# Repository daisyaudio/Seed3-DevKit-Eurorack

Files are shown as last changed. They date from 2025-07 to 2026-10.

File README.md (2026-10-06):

# Seed3 Eurorack Dev Kit

Seed3 Eurorack Dev Kit

## A Eurorack Module Platform for the Daisy Seed3

The Seed3 Eurorack Dev Kit is the premier development board for building your next Eurorack module on the Daisy platform. Create powerful effects, stunning sound sources, and complex utilities, all on a single board.

The Dev Kit carries a host of hardware parameters, including 8 potentiometers, jacks for CV, gate, MIDI, and stereo audio I/O, 2 toggle switches, 2 tactile buttons, and a microSD card reader for sample playback, file generation, and data transfer. Mountable in a standard 3U Eurorack case, the Dev Kit integrates straight into your development rig so you can fully realize your next big Eurorack project.

---

## Contents

- [Features](#features)
- [Specifications](#specifications)
- [Getting Started](#getting-started)
- [Making Your Own Project](#making-your-own-project)
- [Hardware Reference](#hardware-reference)
- [Resources & Support](#resources--support)
- [Open-Source Hardware](#open-source-hardware)
- [License](#license)

---

## Features

| Category | Details |
| --- | --- |
| **Format** | 3U Eurorack, 28HP |
| **Audio** | Stereo audio input and output (AC-coupled) |
| **MIDI** | 3.5mm TRS MIDI In, Out, and Thru |
| **CV & Gate** | 4 × CV inputs, 2 × gate inputs, 2 × CV outputs |
| **USB** | USB-C port connected to the Seed3's external USB peripheral, for USB features in your firmware |
| **Storage** | microSD slot for sample playback, file generation, and data transfer |
| **Potentiometers** | 8 × 10kΩ linear (B-taper) |
| **Buttons** | 2 × tactile switches |
| **Toggle Switches** | 2 × toggle switches (1 × ON-OFF-ON, 1 × ON-ON) |
| **LEDs** | 1 × RGB LED, 1 × single-color LED |

## Specifications

| Parameter | Value |
| --- | --- |
| Processor module | Daisy Seed3 |
| Format | 3U Eurorack, 28HP |
| Power | 10-pin Eurorack power header (+12V / -12V) |
| Current draw | Firmware dependent |
| Reverse polarity protection | Yes |
| Module depth | PCB acts as front panel, can install in 3U space. 2mm behind rails. |
| Audio codec / sample rate | TAC5242 / up to 32-bit, 192kHz |
| Audio input impedance | 100kΩ |
| Audio output impedance | 100Ω |
| Audio level | 10Vpp nominal (Eurorack standard), with headroom up to about 20Vpp |
| CV input range | -5V to +5V |
| CV output range | 0V to +5V |
| Gate input threshold | +0.4V |
| MIDI connectors | 3 × 3.5mm TRS Type A (In, Out, Thru) |

> [!WARNING]
> Check the ribbon cable orientation before powering up. The red stripe marks -12V. Reverse power protection circuit is installed on the board.

## Getting Started

> [!IMPORTANT]
> This kit has two USB-C ports: one on the **Dev Kit board** (J7) and one on the **Seed3 module** itself. Program the template and read its serial output through the **Seed3's** USB-C port.

### 1. Install the toolchain

Follow the Daisy [C++ Getting Started guide](https://docs.daisy.audio/tutorials/cpp-dev-env/). It installs the toolchain and clones [DaisyExamples](https://github.com/daisyaudio/DaisyExamples), which includes [libDaisy](https://github.com/daisyaudio/libDaisy) (hardware library) and [DaisySP](https://github.com/daisyaudio/DaisySP) (DSP library).

### 2. Update libDaisy
 
The Eurorack Dev Kit template and board support are newer than the copy of libDaisy included with DaisyExamples. From your `DaisyExamples` folder, update libDaisy to its latest version, fetch its own dependencies, and rebuild it:
 
```bash
git submodule update --remote libDaisy
git -C libDaisy submodule update --init --recursive
make -C libDaisy
```
 
The first line moves libDaisy to its latest version. The second fetches libDaisy's own dependencies, such as the STM32 drivers it needs to compile. The last line rebuilds libDaisy, which is required after any update.
 
> [!CAUTION]
> Running `git submodule update --init --recursive` or `git pull --recurse-submodules` from the `DaisyExamples` folder afterwards resets libDaisy to the older version DaisyExamples was built with. If that happens, run the three commands above again.

### 3. Build the template

The starting project for this kit is [`examples/devkits/Eurorack-DevKit-Template`](https://github.com/daisyaudio/libDaisy/tree/master/examples/devkits/Eurorack-DevKit-Template). From the `libDaisy` folder:

```bash
cd examples/devkits/Eurorack-DevKit-Template
make
```

This creates `Eurorack-DevKit-Template.bin` in the template's `build/` folder.

### 4. Flash the Seed3

1. Connect a USB-C cable from your computer to the USB-C port on the **Seed3 module**. The Seed3 is powered over USB while you flash, so the module doesn't need to be in a powered case.
2. Hold **BOOT**, press and release **RESET**, then release **BOOT**.
3. From the template folder, run:

   ```bash
   make program-dfu
   ```

   Or, in the [Daisy Web Programmer](https://flash.daisy.audio/), upload the `Eurorack-DevKit-Template.bin` file from the `build/` folder.

### 5. Power up and try it out

Mount the Dev Kit in a 3U Eurorack case and connect the Eurorack power ribbon to the power header (P1) with the red stripe on -12V. You can leave the Seed3's USB cable connected so you can watch the serial output.

The template:

- Passes audio from the inputs straight to the outputs.
- Cycles the colors of the RGB LED (LED1) and blinks LED2.
- Outputs a slow rising ramp on CV Out 1 and a falling ramp on CV Out 2 (about a 2.5-second period).
- Echoes MIDI notes received on MIDI In to MIDI Out.
- Prints the state of every control over USB serial on the Seed3's USB-C port. Open any serial monitor to see it.

## Making Your Own Project

Edits only take effect on the module after you rebuild and reflash, so start your own project from a copy of the template.

1. Copy the `Eurorack-DevKit-Template` folder into your `DaisyExamples` folder and rename it, for example `DaisyExamples/MyModule`.
2. In the copied `Makefile`:
   - Set `TARGET` to your project name, for example `TARGET = MyModule`.
   - Change `LIBDAISY_DIR` to point to libDaisy from the new location: `LIBDAISY_DIR = ../libDaisy`.
   - To use DaisySP, uncomment the DaisySP line and set `DAISYSP_DIR = ../DaisySP`.
3. Write your module in `src/main.cpp`. Audio is processed in `AudioCallback()`: inputs are `in[0][i]` (left) and `in[1][i]` (right), and outputs are `out[0][i]` and `out[1][i]` (see [Audio](#audio)).
4. Rebuild and flash after every change:

   ```bash
   make
   make program-dfu
   ```

   Put the Seed3 into BOOT mode (step 4 above) before each `make program-dfu`.

> [!TIP]
> The template builds with debugging enabled (`DEBUG = 1`, `OPT = -Og`). For release builds, set `DEBUG = 0` and `OPT = -O3` in the Makefile. If your program grows too large for the Seed3's internal flash, see the [Daisy Bootloader guide](https://docs.daisy.audio/tutorials/_a7_Getting-Started-Daisy-Bootloader/).

## Hardware Reference

The **Ref** column lists each part's reference designator, as printed on the board's silkscreen.

### Pinout

Seed3 Eurorack Dev Kit pinout

A printable [Pinout PDF](https://daisy.nyc3.cdn.digitaloceanspaces.com/products/seed-3-euro/seed-3-euro-dev-kit-pinout.pdf) is also available.

### Audio

| Jack | Ref | Signal | Audio Callback |
| --- | --- | --- | --- |
| Input Left | J_AUDIO_IN_L1 | `AUDIO_IN_L` | `in[0][i]` |
| Input Right | J_AUDIO_IN_R1 | `AUDIO_IN_R` | `in[1][i]` |
| Output Left | J_AUDIO_OUT_L1 | `AUDIO_OUT_L` | `out[0][i]` |
| Output Right | J_AUDIO_OUT_R1 | `AUDIO_OUT_R` | `out[1][i]` |

> [!NOTE]
> Input Right is normalled to Input Left. With nothing patched into Input Right, a signal patched into Input Left feeds both channels.

### Potentiometers (8-channel multiplexer)

The eight pots are read through a single ADC pin via an 8-channel analog multiplexer (U12). Set the select lines A/B/C to choose a channel, then read `POT_MUX`.

| Signal | Seed3 Pin |
| --- | --- |
| `POT_MUX` (ADC) | D15 |
| `MUX_CTRL_A` | D24 |
| `MUX_CTRL_B` | D25 |
| `MUX_CTRL_C` | D26 |

| Pot | Ref | Mux Channel |
| --- | --- | --- |
| Potentiometer 1 | VR1 | `MUX_CH_0` |
| Potentiometer 2 | VR2 | `MUX_CH_1` |
| Potentiometer 3 | VR3 | `MUX_CH_2` |
| Potentiometer 4 | VR4 | `MUX_CH_3` |
| Potentiometer 5 | VR5 | `MUX_CH_4` |
| Potentiometer 6 | VR6 | `MUX_CH_5` |
| Potentiometer 7 | VR7 | `MUX_CH_6` |
| Potentiometer 8 | VR8 | `MUX_CH_7` |

### CV & Gates

| Jack | Ref | Signal | Seed3 Pin |
| --- | --- | --- | --- |
| CV In 1 | J_CV_IN_1 | `CV_1_ADC` | D18 |
| CV In 2 | J_CV_IN_2 | `CV_2_ADC` | D17 |
| CV In 3 | J_CV_IN_3 | `CV_3_ADC` | D16 |
| CV In 4 | J_CV_IN_4 | `CV_4_ADC` | D19 |
| Gate In 1 | J_GATE_IN_1 | `GPIO_GATEIN_1` | D10 |
| Gate In 2 | J_GATE_IN_2 | `GPIO_GATEIN_2` | D21 |
| CV Out 1 | J_CV_OUT_1 | `DAC_CV_1` | D23 (DAC channel 1) |
| CV Out 2 | J_CV_OUT_2 | `DAC_CV_2` | D22 (DAC channel 2) |

### Switches

| Switch | Ref | Signal | Seed3 Pin | Type |
| --- | --- | --- | --- | --- |
| Tactile switch 1 | SW1 | `TAC_SW1` | D0 | Momentary |
| Tactile switch 2 | SW2 | `TAC_SW2` | D20 | Momentary |
| Toggle switch 1 | SW3 | `TOG_2_A` / `TOG_2_B` | D27 / D7 | ON-OFF-ON (3-position, two pins) |
| Toggle switch 2 | SW4 | `TOG_1` | D12 | ON-ON |

### LEDs

| LED | Ref | Signal | Seed3 Pin |
| --- | --- | --- | --- |
| RGB LED — Red | LED1 | `LED_R` | D9 |
| RGB LED — Green | LED1 | `LED_G` | D28 |
| RGB LED — Blue | LED1 | `LED_B` | D8 |
| Single-color LED | LED2 | `LED_MONO_1` | D11 |

### MIDI

| Jack | Ref | Signal | Seed3 Pin | Direction |
| --- | --- | --- | --- | --- |
| MIDI Out | J_MIDI_OUT1 | `MIDI_TX` | D13 | Out |
| MIDI In | J_MIDI_IN1 | `MIDI_RX` | D14 | In |
| MIDI Thru | J_MIDI_THRU1 | `MIDI_RX` | D14 | Mirrors MIDI In |

### microSD (SDMMC, 4-bit)

| Signal | Seed3 Pin |
| --- | --- |
| `SDMMC_CK` | D6 |
| `SDMMC_CMD` | D5 |
| `SDMMC_D0` | D4 |
| `SDMMC_D1` | D3 |
| `SDMMC_D2` | D2 |
| `SDMMC_D3` | D1 |

### USB-C

The Dev Kit's USB-C port (J7) connects to the Seed3's external USB peripheral. It is separate from the USB-C port on the Seed3 module, which is used for programming and for the template's serial output. The module is powered from the Eurorack power header (P1), not from USB.

| Signal | Seed3 Pin |
| --- | --- |
| `USB_OTG_HS_N` | D29 |
| `USB_OTG_HS_P` | D30 |

## Resources & Support

- **Product Page:** [Seed3 Eurorack Dev Kit](https://daisy.audio/products/seed-3-eurorack-dev-kit)
- **Documentation:** [docs.daisy.audio](https://docs.daisy.audio/product/Seed3-Euro-Dev-Kit/)
- **Community Forum:** [community.daisy.audio](https://community.daisy.audio)
- **Discord:** [Daisy Discord](https://discord.gg/ByHBnMtQTR)
- **Issues:** Report bugs or hardware errata via this repository's [Issues](../../issues) tab.

### Design Files

- [Schematic (PDF)](https://daisy.nyc3.cdn.digitaloceanspaces.com/products/seed-3-euro/Seed3-DevKit-Eurorack-Rev3.pdf)
- [Bill of Materials (CSV)](https://daisy.nyc3.cdn.digitaloceanspaces.com/products/seed-3-euro/Seed3-DevKit-Eurorack_Rev3-bom.csv)
- [Pinout (PDF)](https://daisy.nyc3.cdn.digitaloceanspaces.com/products/seed-3-euro/seed-3-euro-dev-kit-pinout.pdf)
- [KiCad Design Files](https://github.com/daisyaudio/ES-Seed3-DevKit-Eurorack/releases/latest)

---

## Open-Source Hardware

Open Source Hardware logo

The Eurorack Dev Kit is open-source hardware, built to the [Open Source Hardware Definition](https://www.oshwa.org/definition/) published by the Open Source Hardware Association (OSHWA). The schematics, PCB layouts, bill of materials, and KiCad source files are published so that you can study, modify, manufacture, and sell your own designs based on them.

## License

Copyright © 2026 Qu-Bit Electronix, Inc. (dba Daisy)

The hardware design files in this repository are licensed under the **CERN Open Hardware Licence Version 2 – Permissive** ([CERN-OHL-P-2.0](https://ohwr.org/cern_ohl_p_v2.pdf)).

Subject to the terms of that licence, you may:

- Use, study, copy, modify, and distribute these designs and any products made from them.
- Incorporate these designs, in whole or in part, into closed-source and commercial products.

When you redistribute these designs or products made from them, you must:

- Retain all copyright, licence, and other notices contained in the source files.
- Add a notice to any modified source stating that you modified it, with the date and a brief description of the change.
- Ensure that recipients of any product made from these designs have access to the applicable notices.

These designs are provided "as is", without warranty of any kind, express or implied. See [LICENSE](LICENSE.txt) for the full licence text, including the disclaimer of warranty and limitation of liability.

Firmware and software, including [libDaisy](https://github.com/daisyaudio/libDaisy) and [DaisySP](https://github.com/daisyaudio/DaisySP), are licensed separately under the terms included in their respective repositories.

SPDX-License-Identifier: CERN-OHL-P-2.0

### Trademarks

DAISY® is a trademark of Qu-Bit Electronix, Inc., registered in the United States. CERN-OHL-P-2.0 grants a license to the copyright and related rights in these designs. It does not grant any right or license to use the DAISY name, logos, product names, or other trademarks of Qu-Bit Electronix, Inc.

Products, derivative designs, and related materials made from these designs may not:

- Use the DAISY name or logo, or any confusingly similar name or mark, in a product name, model number, brand, domain name, or marketing material.
- Reproduce the DAISY name or logo on a PCB silkscreen, front panel, enclosure, packaging, or documentation, except where needed to keep the required licence notices.
- State or imply that the product is made, endorsed, sponsored, certified, or supported by Qu-Bit Electronix, Inc.

You may make truthful, factual statements about compatibility or origin, such as "based on the Seed3 Eurorack Dev Kit design" or "compatible with the Daisy Seed3", provided the statement does not suggest affiliation or endorsement. If you redistribute or sell products derived from these designs, remove the DAISY name and logo from the silkscreen and other artwork before manufacture.

For trademark licensing or permission requests, contact Qu-Bit Electronix, Inc. through [daisy.audio/pages/support](https://daisy.audio/pages/support).

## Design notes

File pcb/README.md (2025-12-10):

# PCB changelog

## Rev2

- Fixed Height of the module to be eurorack frontpanel standard (128.5mm)
- Fixed R73 resistor value typo for gain level (is now 100K)
- Re-laid out entire module to look good with the new height, and fix the issue
  with the CV Out 1 jack being too close to the daisy (alignment should be good)
- Updated QR code with new redirect link
- Properly grounded the INH pin of the CD4051
- Added Daisy software mappings to the silkscreen
- Updated rev text
- Swapped CV out 1 and 2 from the seed so that the software channel matches the hardware label

## Rev1

Initial Revision

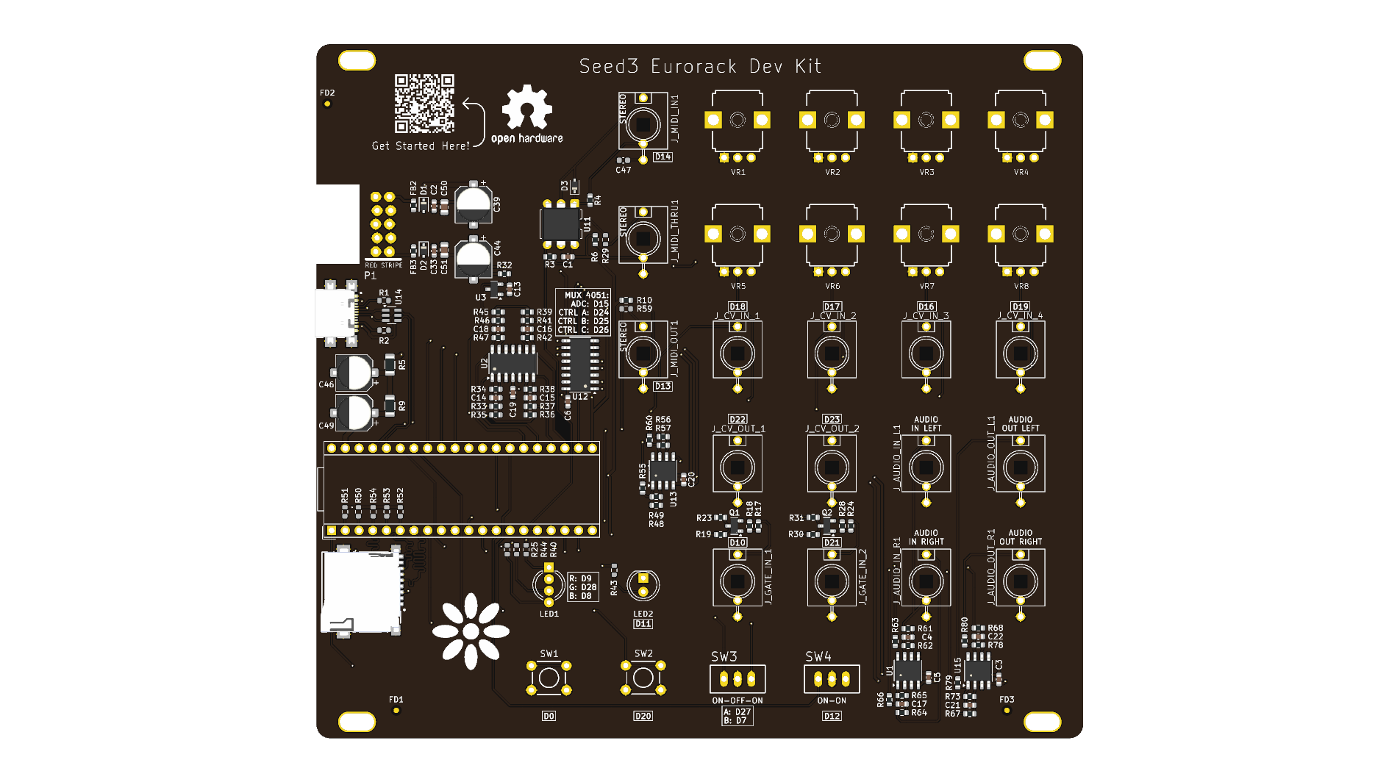
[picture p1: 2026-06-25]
pcb/Seed3-DevKit-Eurorack-Rev3/review/2026-06-18/board-render/render_top.png

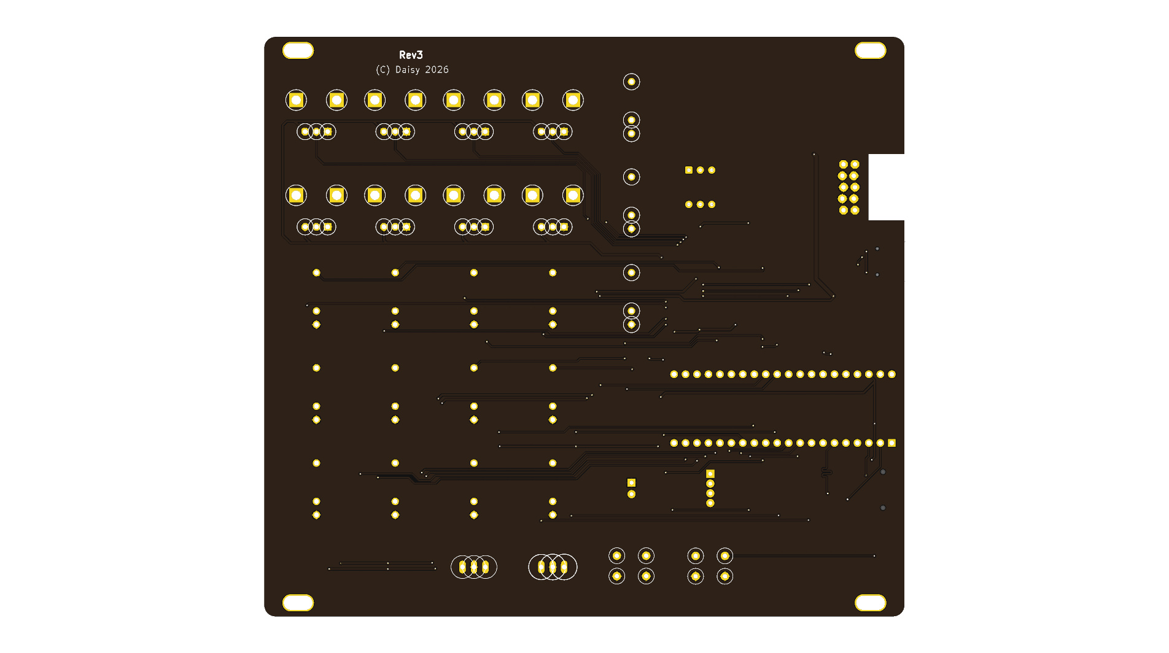
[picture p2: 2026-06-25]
pcb/Seed3-DevKit-Eurorack-Rev3/review/2026-06-18/board-render/render_bottom.png

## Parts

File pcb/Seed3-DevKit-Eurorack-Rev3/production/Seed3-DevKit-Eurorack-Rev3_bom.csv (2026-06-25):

Value | Reference | Footprint | Qty | AVL_Part_Number
 | J_AUDIO_IN_L1,J_AUDIO_IN_R1,J_AUDIO_OUT_L1,J_AUDIO_OUT_R1,J_CV_IN_1,J_CV_IN_2,J_CV_IN_3,J_CV_IN_4,J_CV_OUT_1,J_CV_OUT_2,J_GATE_IN_1,J_GATE_IN_2 | Electrosmith-Interface:S_JACK | 12
 | J_MIDI_IN1,J_MIDI_OUT1,J_MIDI_THRU1 | Electrosmith-Interface:STEREO_JACK_3.5MM | 3
 | P1 | Electrosmith-Connectors:EURO_PWR_HEADER_LOCK | 1
1NF | C14,C15,C16,C18 | Capacitor_SMD:C_0603_1608Metric | 4 | 1NF C0603
3R3 | R5,R9 | Resistor_SMD:R_1206_3216Metric | 2 | 3R3
10R | R6,R10,R29,R59 | Resistor_SMD:R_0603_1608Metric | 4 | 10R R0603
10UF | C50,C51 | Capacitor_SMD:C_0805_2012Metric | 2 | 10UF C0805
100UF | C39,C44,C46,C49 | Capacitor_SMD:CP_Elec_6.3x7.7 | 4 | 100UF
100R | R23,R31,R55,R60,R63,R66,R79,R80 | Resistor_SMD:R_0603_1608Metric | 8 | 100R R0603
100NF | C1,C2,C3,C5,C6,C13,C19,C20,C33,C47 | Capacitor_SMD:C_0603_1608Metric | 10 | 100NF C0603
220R | R4 | Resistor_SMD:R_0603_1608Metric | 1 | 220R R0603
270R | R3 | Resistor_SMD:R_0603_1608Metric | 1 | 270R R0603
2K | R25,R32,R40,R43,R44 | Resistor_SMD:R_0603_1608Metric | 5 | 2K R0603
5K1 | R1,R2 | Resistor_SMD:R_0603_1608Metric | 2 | 5K1 R0603
10K | R19,R30,R62,R65,R67,R68 | Resistor_SMD:R_0603_1608Metric | 6 | 10K R0603
33K | R34,R38,R42,R47 | Resistor_SMD:R_0603_1608Metric | 4 | 33K R0603
47K | R50,R51,R52,R53,R54 | Resistor_SMD:R_0603_1608Metric | 5 | 47K R0603
62K | R49,R57 | Resistor_SMD:R_0603_1608Metric | 2 | 62K R0603
100K | R17,R24,R33,R37,R41,R46,R61,R64,R73 | Resistor_SMD:R_0603_1608Metric | 9 | 100K R0603
100k | R78 | Resistor_SMD:R_0603_1608Metric | 1 | 100k R0603
120K | R48,R56 | Resistor_SMD:R_0603_1608Metric | 2 | 120K R0603
200K | R35,R36,R39,R45 | Resistor_SMD:R_0603_1608Metric | 4 | 200K R0603
1M | R18,R28 | Resistor_SMD:R_0603_1608Metric | 2 | 1M R0603
33PF | C21,C22 | Capacitor_SMD:C_0603_1608Metric | 2 | 33PF C0603
330PF | C4,C17 | Capacitor_SMD:C_0603_1608Metric | 2 | 330PF C0603
CD4051B | U12 | Package_SO:SOIC-16_3.9x9.9mm_P1.27mm | 1 | CD4051B
Electrosmith_Daisy_Seed_Rev4 | A1 | Module:Electrosmith_Daisy_Seed | 1 | Electrosmith_Daisy_Seed_Rev4
FERRITE_BEAD_0603 | FB2,FB3 | Resistor_SMD:R_0603_1608Metric | 2 | FERRITE_BEAD_0603 R0603
H11L1 | U11 | Package_DIP:DIP-6_W7.62mm | 1 | H11L1
LED | LED2 | LED_THT:LED_D5.0mm | 1 | LED
LED_RKBG | LED1 | LED_THT:LED_D5.0mm-4_RGB_Wide_Pins | 1 | LED_RKBG
LM4040DBZ-10 | U3 | Package_TO_SOT_SMD:SOT-23 | 1 | LM4040DBZ-10
MCP6004 | U2 | Package_SO:SO-14_3.9x8.65mm_P1.27mm | 1 | MCP6004
MICRO_SD_CARD | U7 | TF-01A:TF-01A | 1 | MICRO_SD_CARD
MMBT3904 | Q1,Q2 | Package_TO_SOT_SMD:SOT-23 | 2 | MMBT3904
NSR1020MW2T3G | D1,D2,D3 | Diode_SMD:D_SOD-323 | 3 | NSR1020MW2T3G
P-10K-B-R | VR1,VR2,VR3,VR4,VR5,VR6,VR7,VR8 | parts-for-kicad:9MM_SNAP-IN_POT_SILK | 8 | P-10K-B-R
PTH Mini Button | SW1,SW2 | parts-for-kicad:TL1105SPF250Q_SILK | 2 | PTH Mini Button
TL072 | U1,U13,U15 | Package_SO:SO-8_3.9x4.9mm_P1.27mm | 3 | TL072
TOGGLE_ON-ON_PIP3 | SW4 | parts-for-kicad:TOGGLE_ON-ON_SILK | 1 | TOGGLE_ON-ON_PIP3
TOGGLE_ON_OFF_ON_PIP2 | SW3 | parts-for-kicad:TOGGLE_ON_OFF_ON_SILK | 1 | TOGGLE_ON_OFF_ON_PIP2
USB4110GFA | J7 | USB4110GFA:GCT_USB4110GFA | 1 | USB4110GFA
USBLC6-2SC6 | U14 | Package_TO_SOT_SMD:SOT-23-6 | 1 | USBLC6-2SC6

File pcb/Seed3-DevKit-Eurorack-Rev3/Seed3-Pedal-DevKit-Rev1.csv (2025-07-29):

Id | Designator | Footprint | Quantity | Designation | Supplier and ref
1 | R46,R8,R48,R13,R72,R27,R76,R16,R55 | R_0603_1608Metric | 9 | 100R
2 | FD3,FD1,FD2 | Fiducial_1mm_Mask2mm | 3 | FIDUCIAL
3 | C46 | C_0603_1608Metric | 1 | 10NF
4 | R61,R57,R62,R29,R28,R59,R63 | R_0603_1608Metric | 7 | 10R
5 | SW4,SW3 | TL3301SPF160QJ | 2 | SMT Mini Button
6 | C30,C9,C28,C8 | C_0603_1608Metric | 4 | 1NF
7 | R77,R26,R56,R22,R14,R69,R65,R5,R19,R17,R68,R70,R64 | R_0603_1608Metric | 13 | 10K
8 | Q1,Q5 | SOT-23 | 2 | 3904
9 | C5,C38 | C_0603_1608Metric | 2 | 100PF
10 | C31,C47,C33,C20,C2,C25,C34,C22,C4,C16,C17,C1 | C_0603_1608Metric | 12 | 100NF
11 | R50,R51,R52,R54,R53 | R_0603_1608Metric | 5 | 47K
12 | C27,C24,C43,C36,C14,C21,C39,C13,C41,C23 | CP_Elec_6.3x7.7 | 10 | 100UF
13 | U3,U10,U9 | SOIC-8_5.275x5.275mm_P1.27mm | 3 | OPA1652
14 | FB2,FB5,FB8,FB1,FB9,FB10,FB3,FB4,FB7 | R_0603_1608Metric | 9 | FERRITE_BEAD_0603
15 | R2,R1 | R_0603_1608Metric | 2 | 5K1
16 | H1,H2,H3,H4 | MountingHole_3.5mm_Pad | 4 | MOUNT-PAD-ROUND3.5
17 | LOGO1 | OSHW-LOGO-L_TEXT | 1 | OSHW-LOGO
18 | J5,J2,J6,J3,J4 | TRS_JACK_WQP-PJ609B | 5 | JACK_TRS_SWITCHING
19 | C12,C37 | C_0603_1608Metric | 2 | 33NF
20 | J11,J1,J10 | 57PC5F | 3 | DIN_MIDI_5P
21 | VR3,VR5,VR1,VR4,VR6,VR2 | 9MM_SNAP-IN_POT_SILK_PIP | 6 | P-10K-B-R-PIP
22 | R44,R9,R43,R10,R24,R23,R40,R25 | R_0603_1608Metric | 8 | 2K
23 | R60 | R_0603_1608Metric | 1 | 20K
24 | SW2,SW6 | TOGGLE_SILK_PIP3 | 2 | TOGGLE_ON-ON_PIP3
25 | U8 | SOT-223-3_TabPin2 | 1 | LD1117-5V
26 | R21,R71 | R_0603_1608Metric | 2 | 4K7
27 | R7,R15,R18 | R_0603_1608Metric | 3 | 1M
28 | C29,C48,C10,C42,C7,C35,C6,C3 | CP_Elec_4x5.8 | 8 | 10uF
29 | D6,D5 | D_SOD-323 | 2 | NSR1020MW2T3G
30 | LED1 | LED_D5.0mm | 1 | LED
31 | R11,R74 | R_0603_1608Metric | 2 | 15K
32 | A1 | Electrosmith_Daisy_Seed | 1 | Electrosmith_Daisy_Seed_Rev4
33 | C11,C32 | C_0603_1608Metric | 2 | 270PF
34 | U6,U5 | RELAY-SMD_G6K-2F-Y | 2 | G6K-2F-Y-TR DC3
35 | C26,C15 | C_0805_2012Metric | 2 | 10UF
36 | R75,R12 | R_0603_1608Metric | 2 | 24K
37 | R58,R20 | R_0603_1608Metric | 2 | 3K3
38 | D3,D4 | D_SOD-323 | 2 | 1N4148
39 | U11 | DIP-6_W7.62mm | 1 | H11L1
40 | FSW_1,FSW_2 | S02P | 2 | M12 SPST Footswitch Assembly
41 | U14 | SOT-23-6 | 1 | USBLC6-2SC6
42 | C55 | C_0603_1608Metric | 1 | 1UF
43 | SW1 | TOGGLE_SILK_PIP3 | 1 | TOGGLE_ON_OFF_ON_PIP2
44 | R3 | R_0603_1608Metric | 1 | 270R
45 | C18,C19 | CP_Elec_4x5.8 | 2 | 10UF
46 | LED2 | LED_D5.0mm-4_RGB_Wide_Pins | 1 | LED_RKBG
47 | U1 | SOIC-8_5.275x5.275mm_P1.27mm | 1 | MCP6002-xSN
48 | L2 | SDR0805 | 1 | SDR0805-102KL
49 | U7 | MEM2061-01-188-00-A_GCT | 1 | MICRO_SD_CARD
50 | J8 | BarrelJack_Wuerth_6941xx301002 | 1 | Barrel_Jack_Switch
51 | U4 | USB-C-SMD_G-SWITCH_GT-USB-7010ASV | 1 | GT-USB-7010ASV
52 | R4 | R_0603_1608Metric | 1 | 220R

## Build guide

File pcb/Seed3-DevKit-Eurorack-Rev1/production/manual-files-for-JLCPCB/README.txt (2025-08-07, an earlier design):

We had to re-order the order.
So I was able to quickly make a BOM that had the JLCPCB PNs in it.
It is here.

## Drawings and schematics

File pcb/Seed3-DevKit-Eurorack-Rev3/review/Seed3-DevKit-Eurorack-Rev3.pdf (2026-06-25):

Peripherals File: Seed3-DevKit-Eurorack_2.kicad_sch | Power File: Seed3-DevKit-Eurorack_4.kicad_sch

Daisy File: Seed3-DevKit-Eurorack_1.kicad_sch

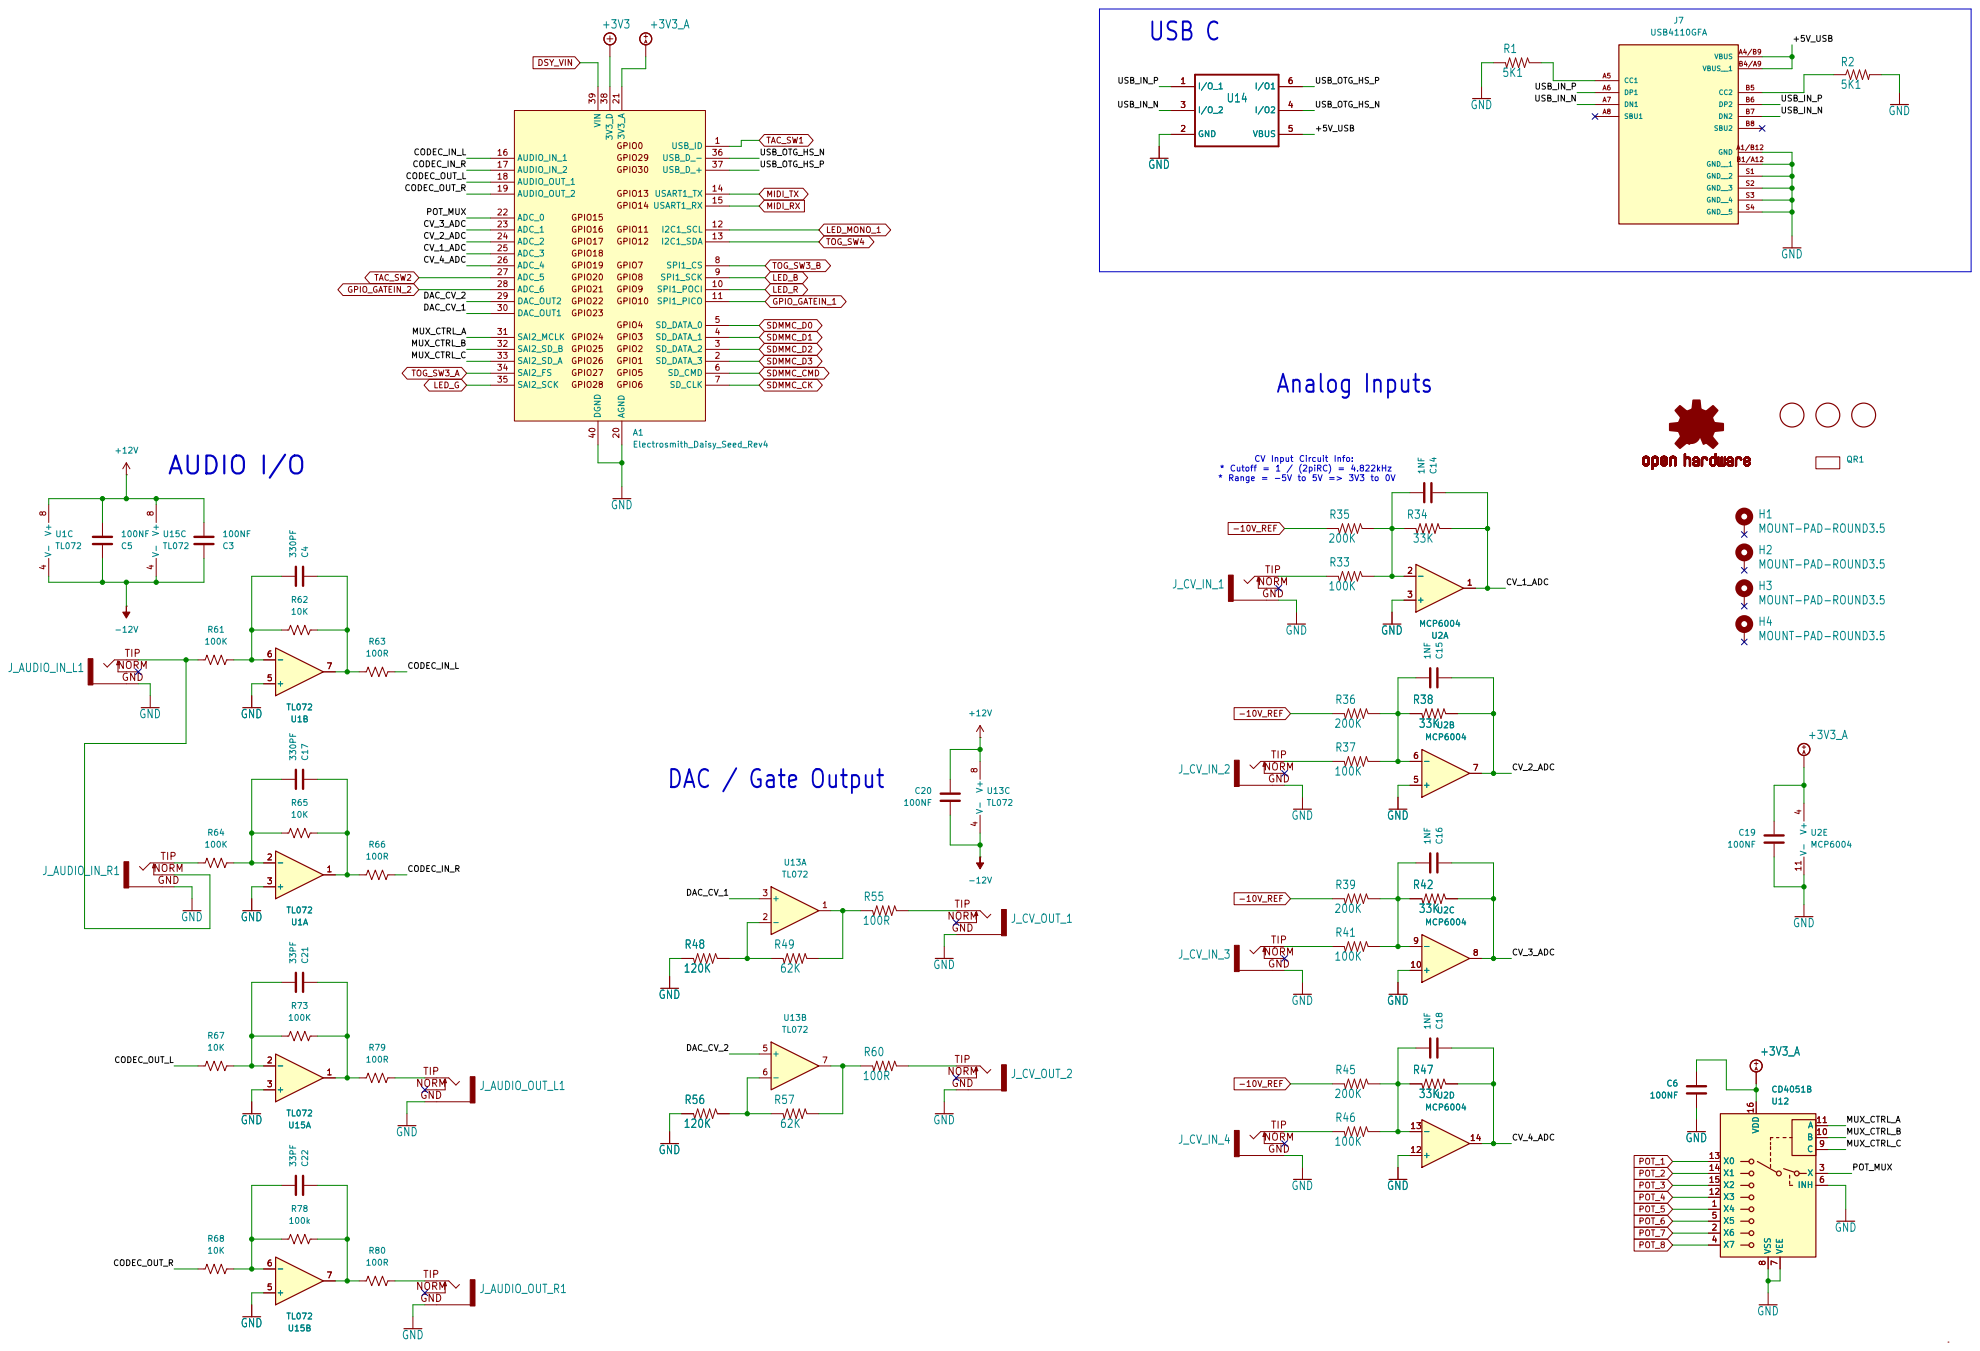
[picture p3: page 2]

* Range = -5V to 5V => 3V3 to 0V USB C

CV Input Circuit Info: * Cutoff = 1 / (2piRC) = 4.822kHz

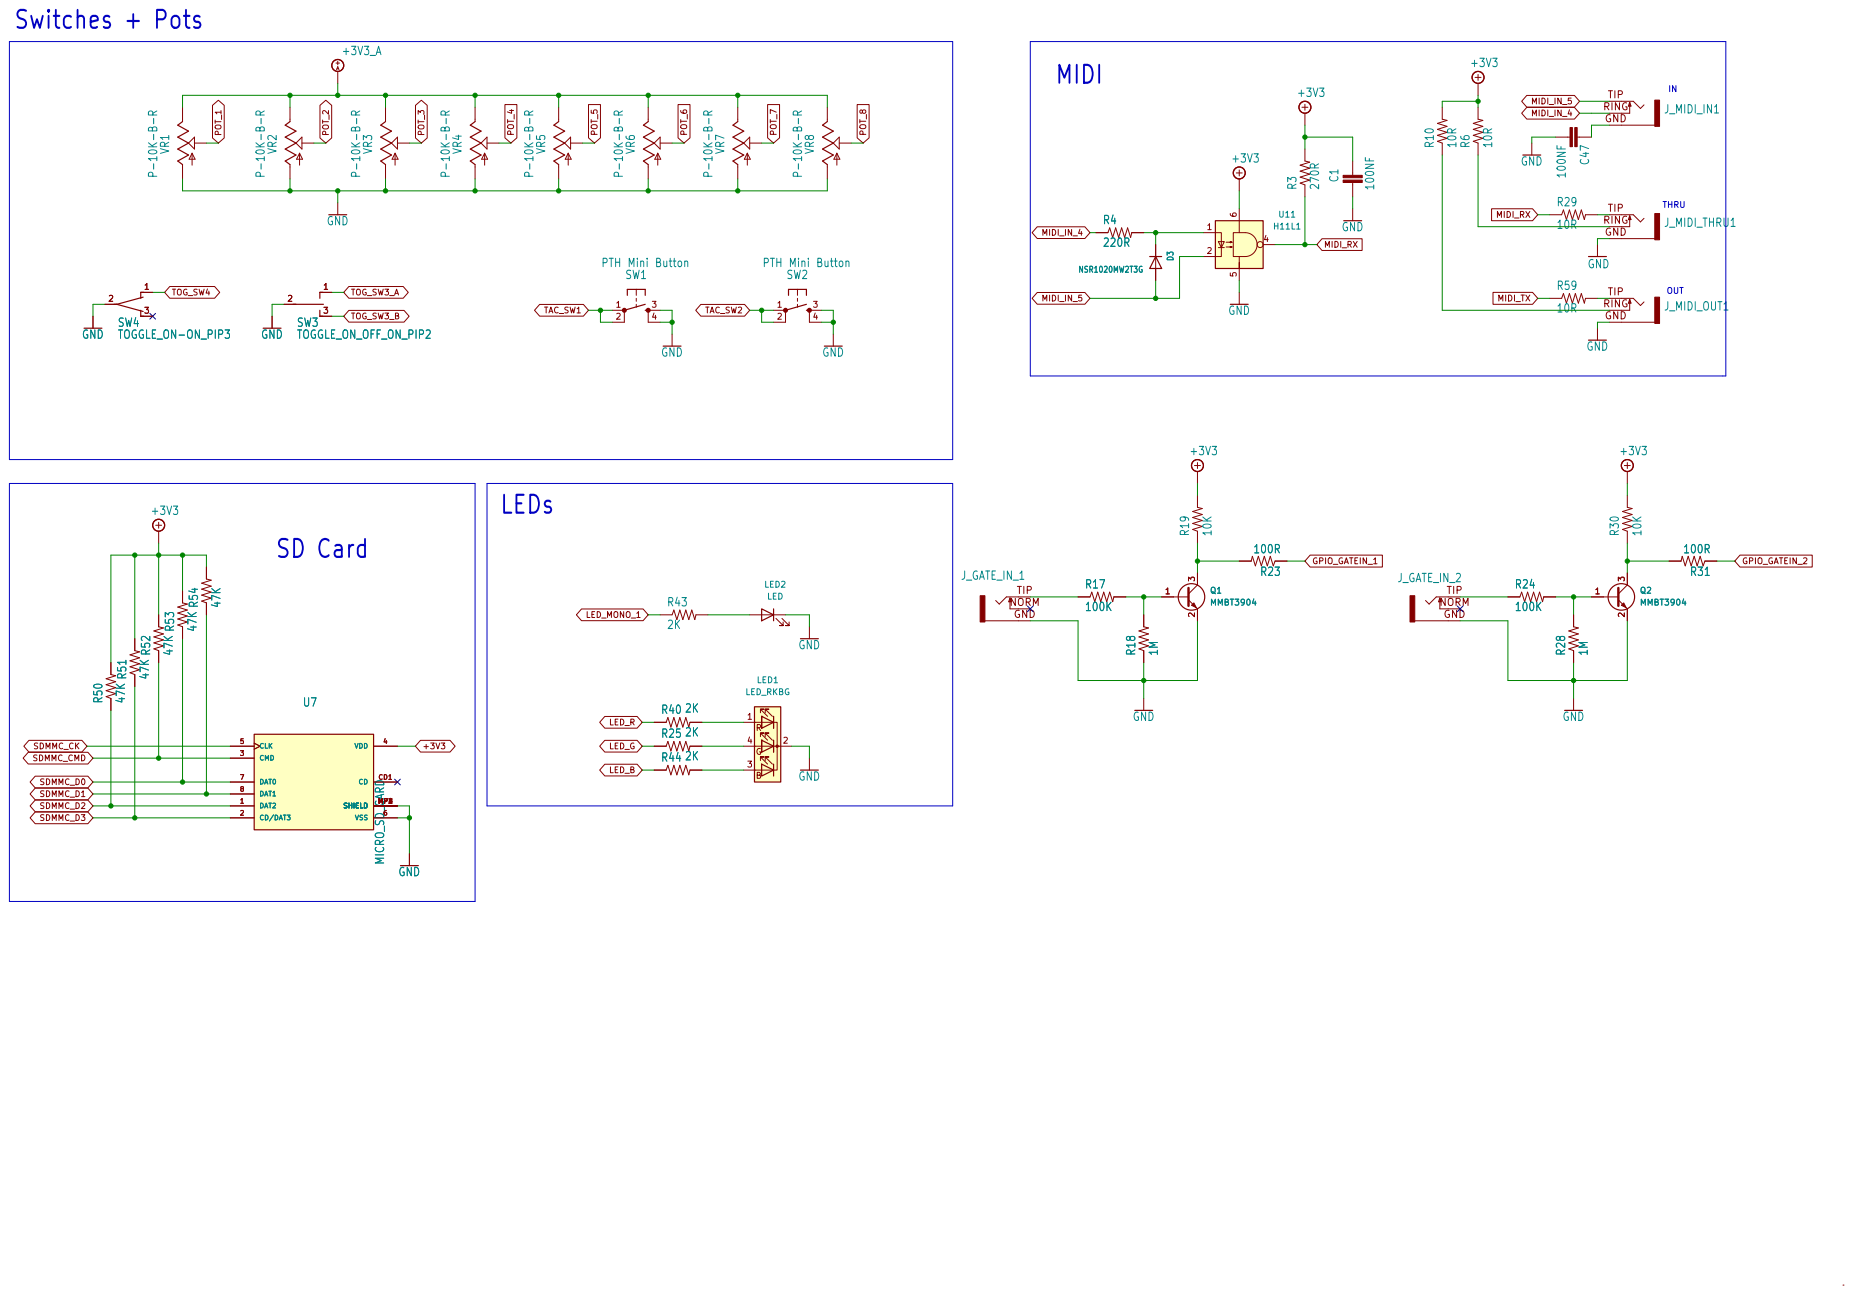
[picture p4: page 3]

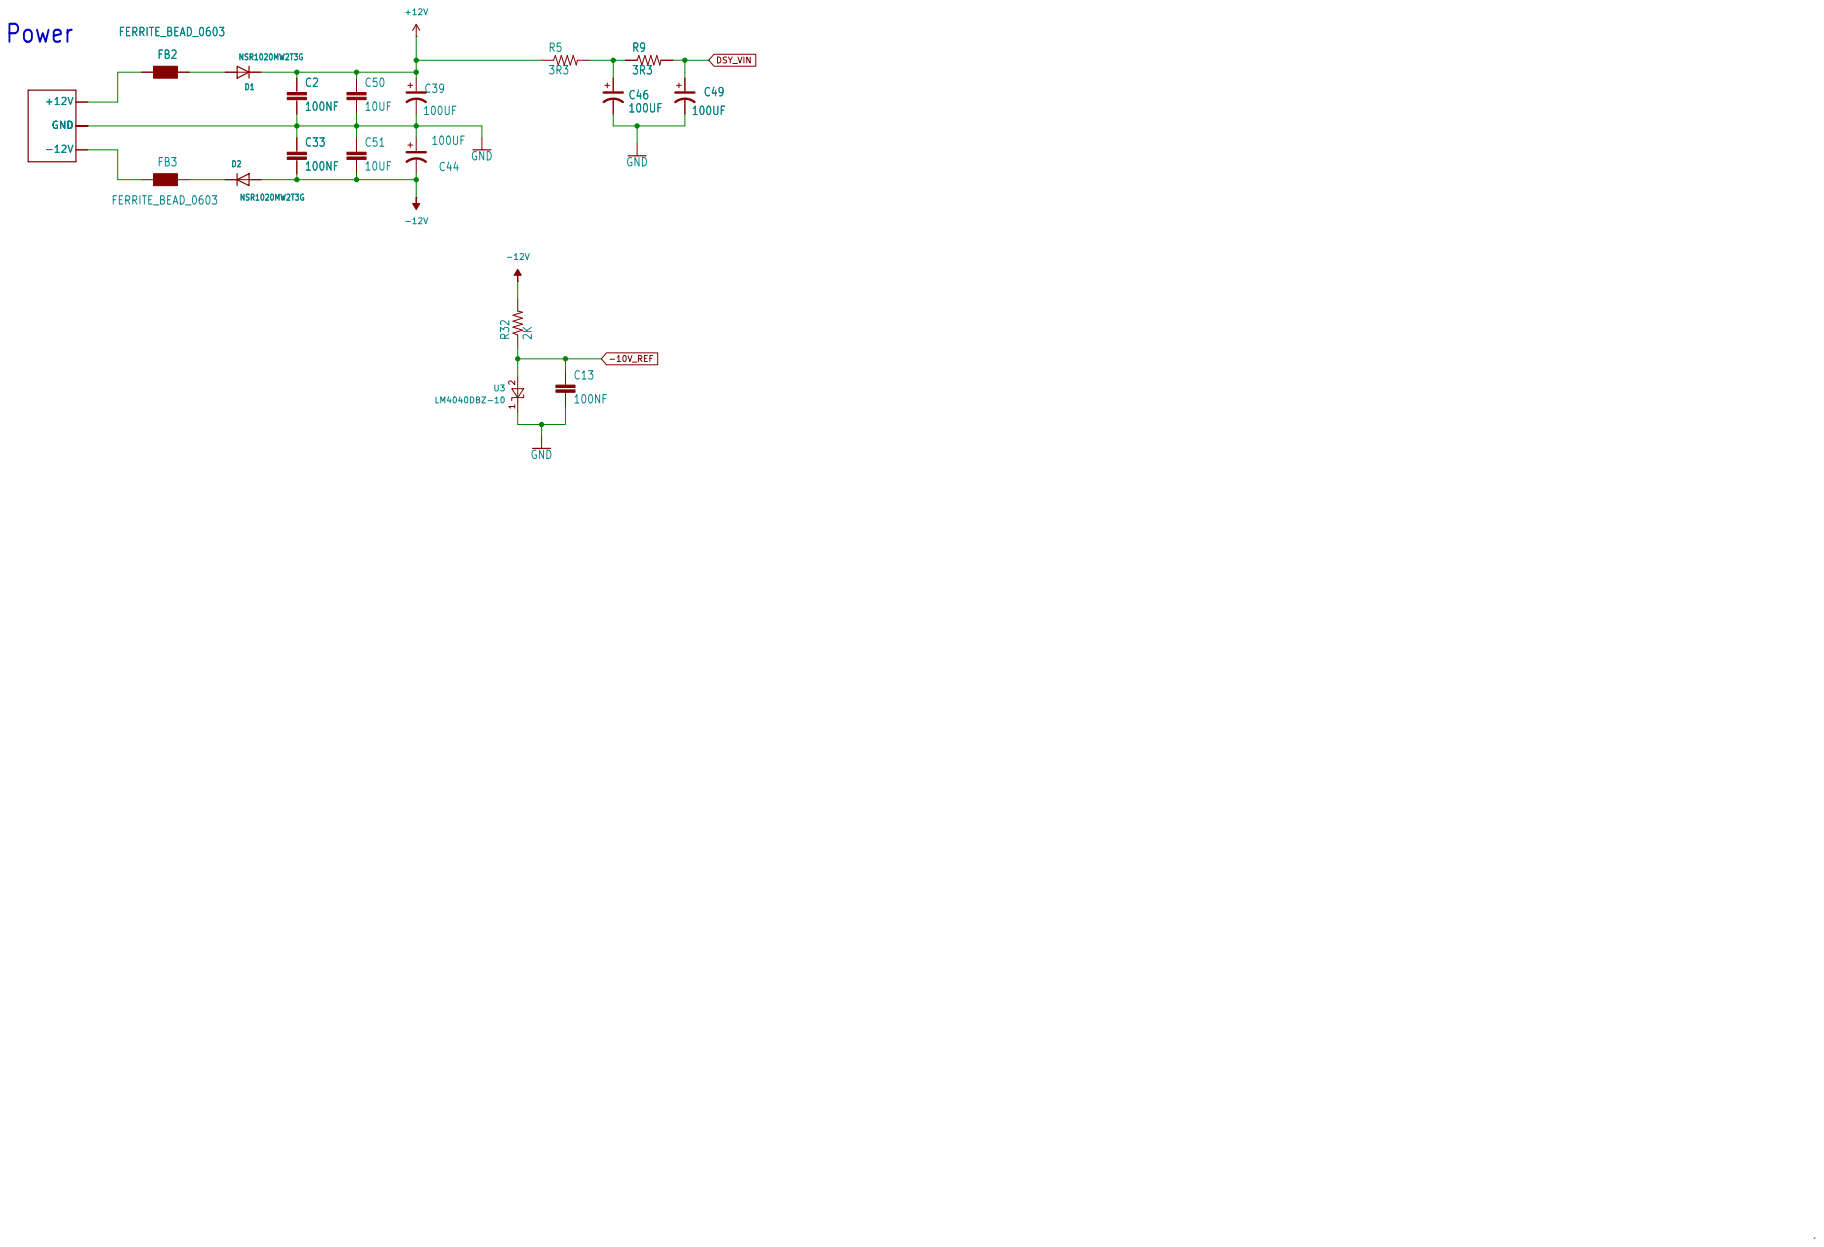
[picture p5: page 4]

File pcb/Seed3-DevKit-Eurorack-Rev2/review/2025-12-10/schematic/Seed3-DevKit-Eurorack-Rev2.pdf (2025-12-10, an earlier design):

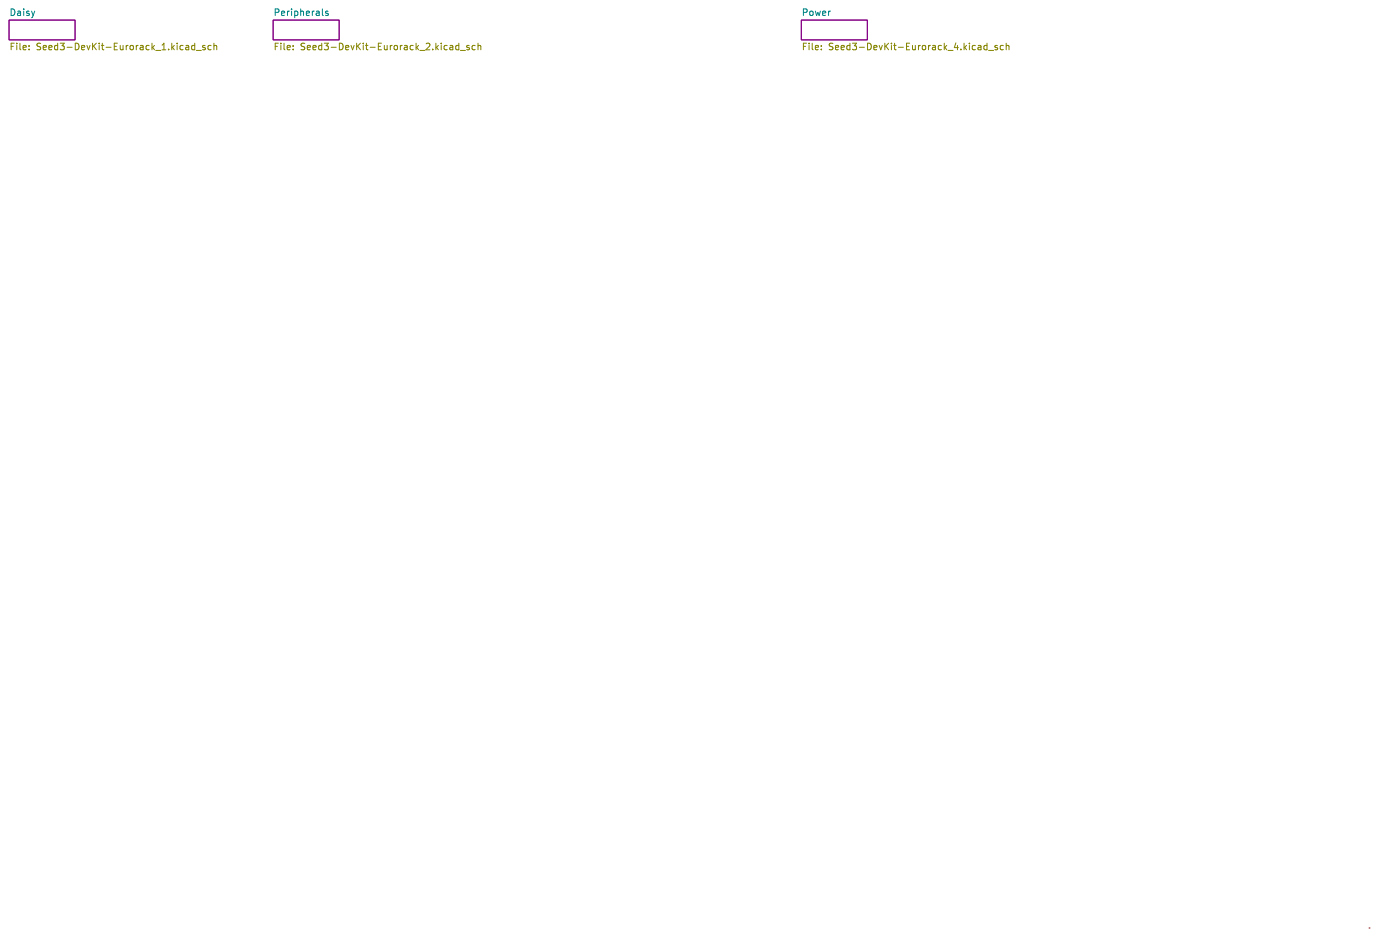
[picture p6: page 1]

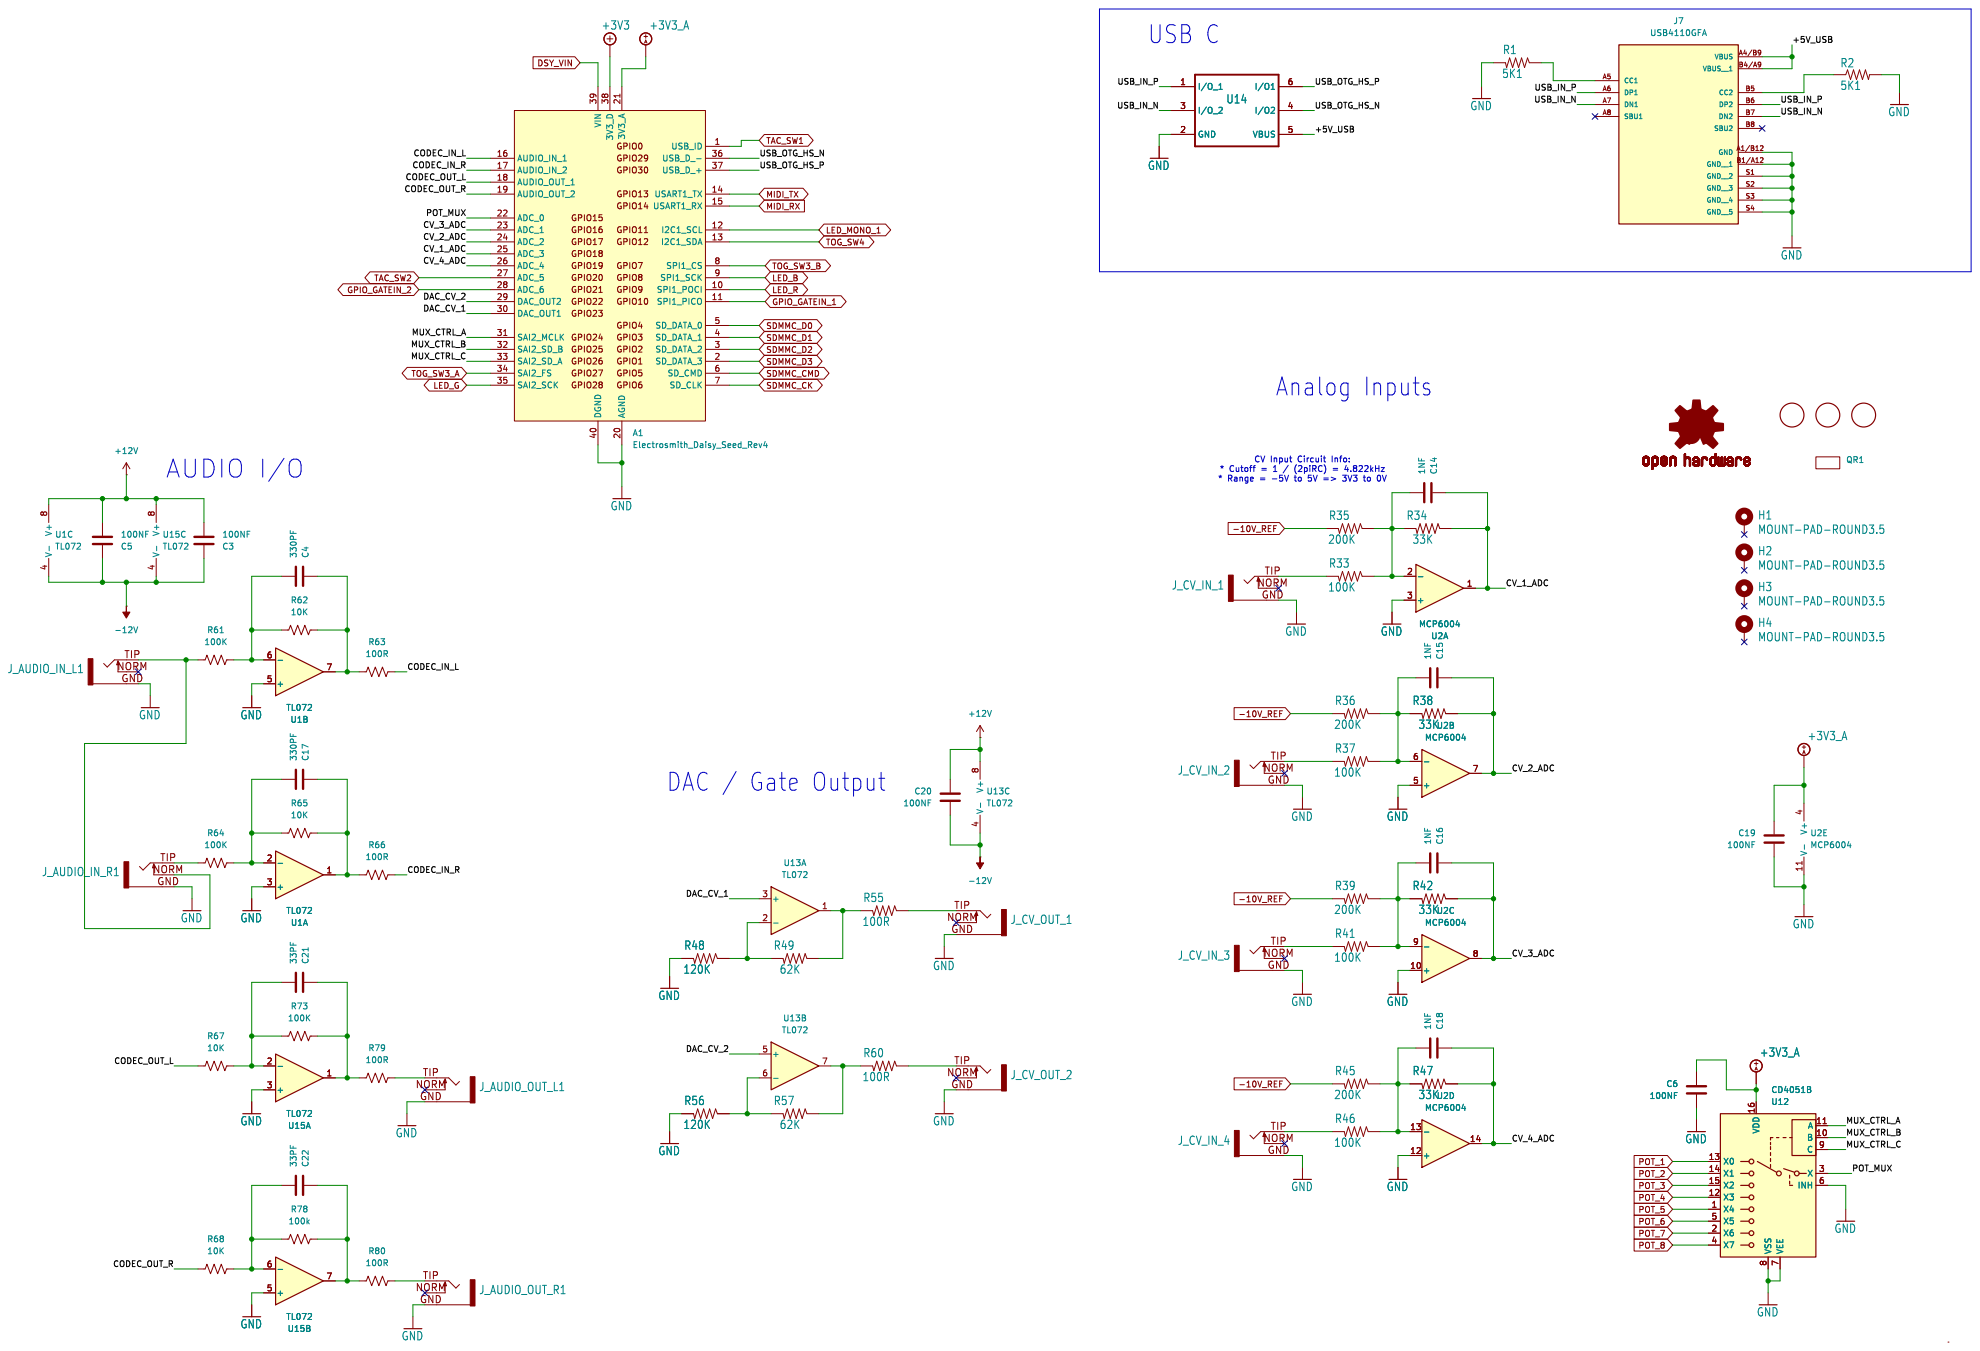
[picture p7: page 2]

* Range = -5V to 5V => 3V3 to 0V USB C

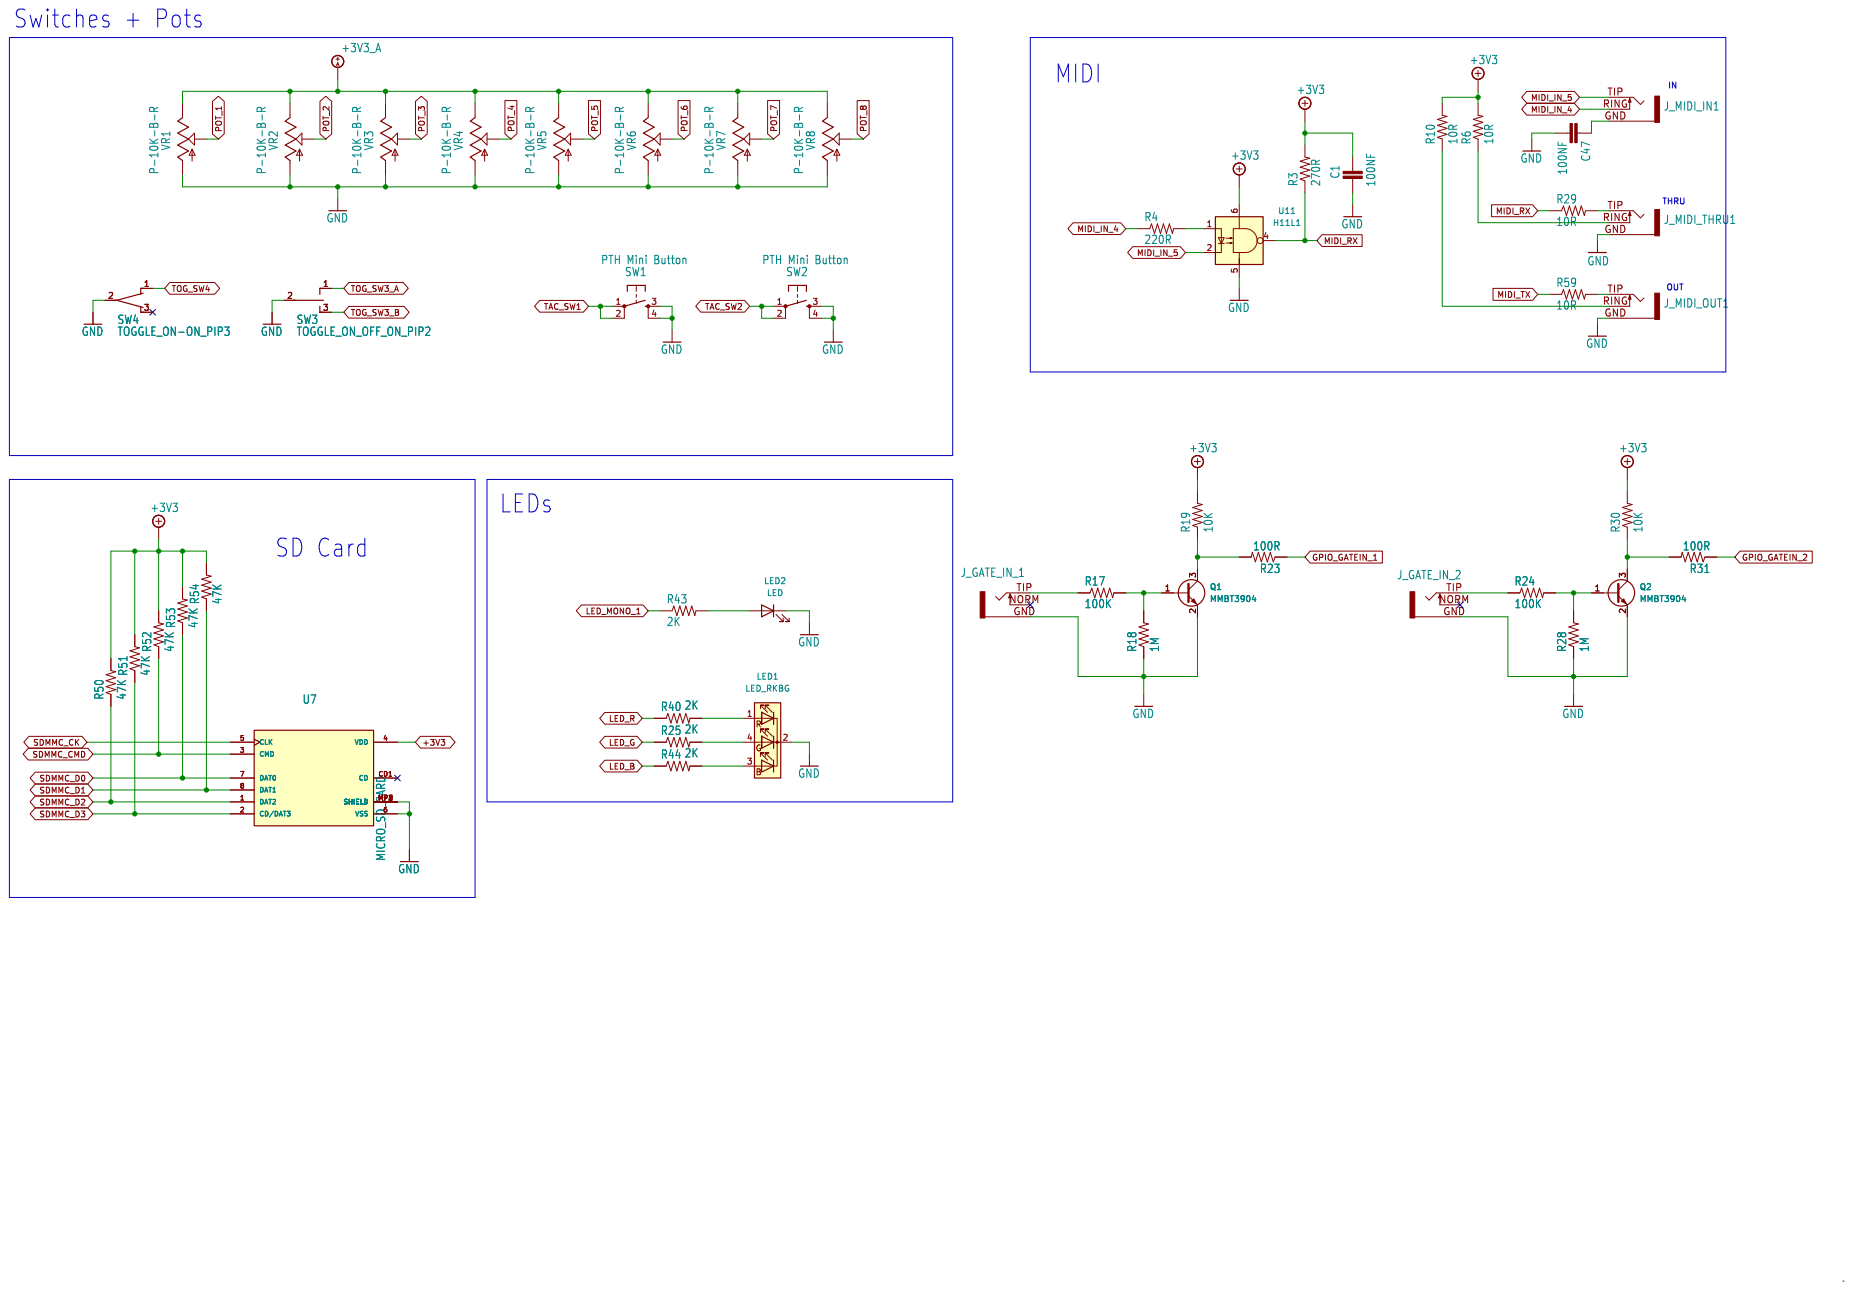
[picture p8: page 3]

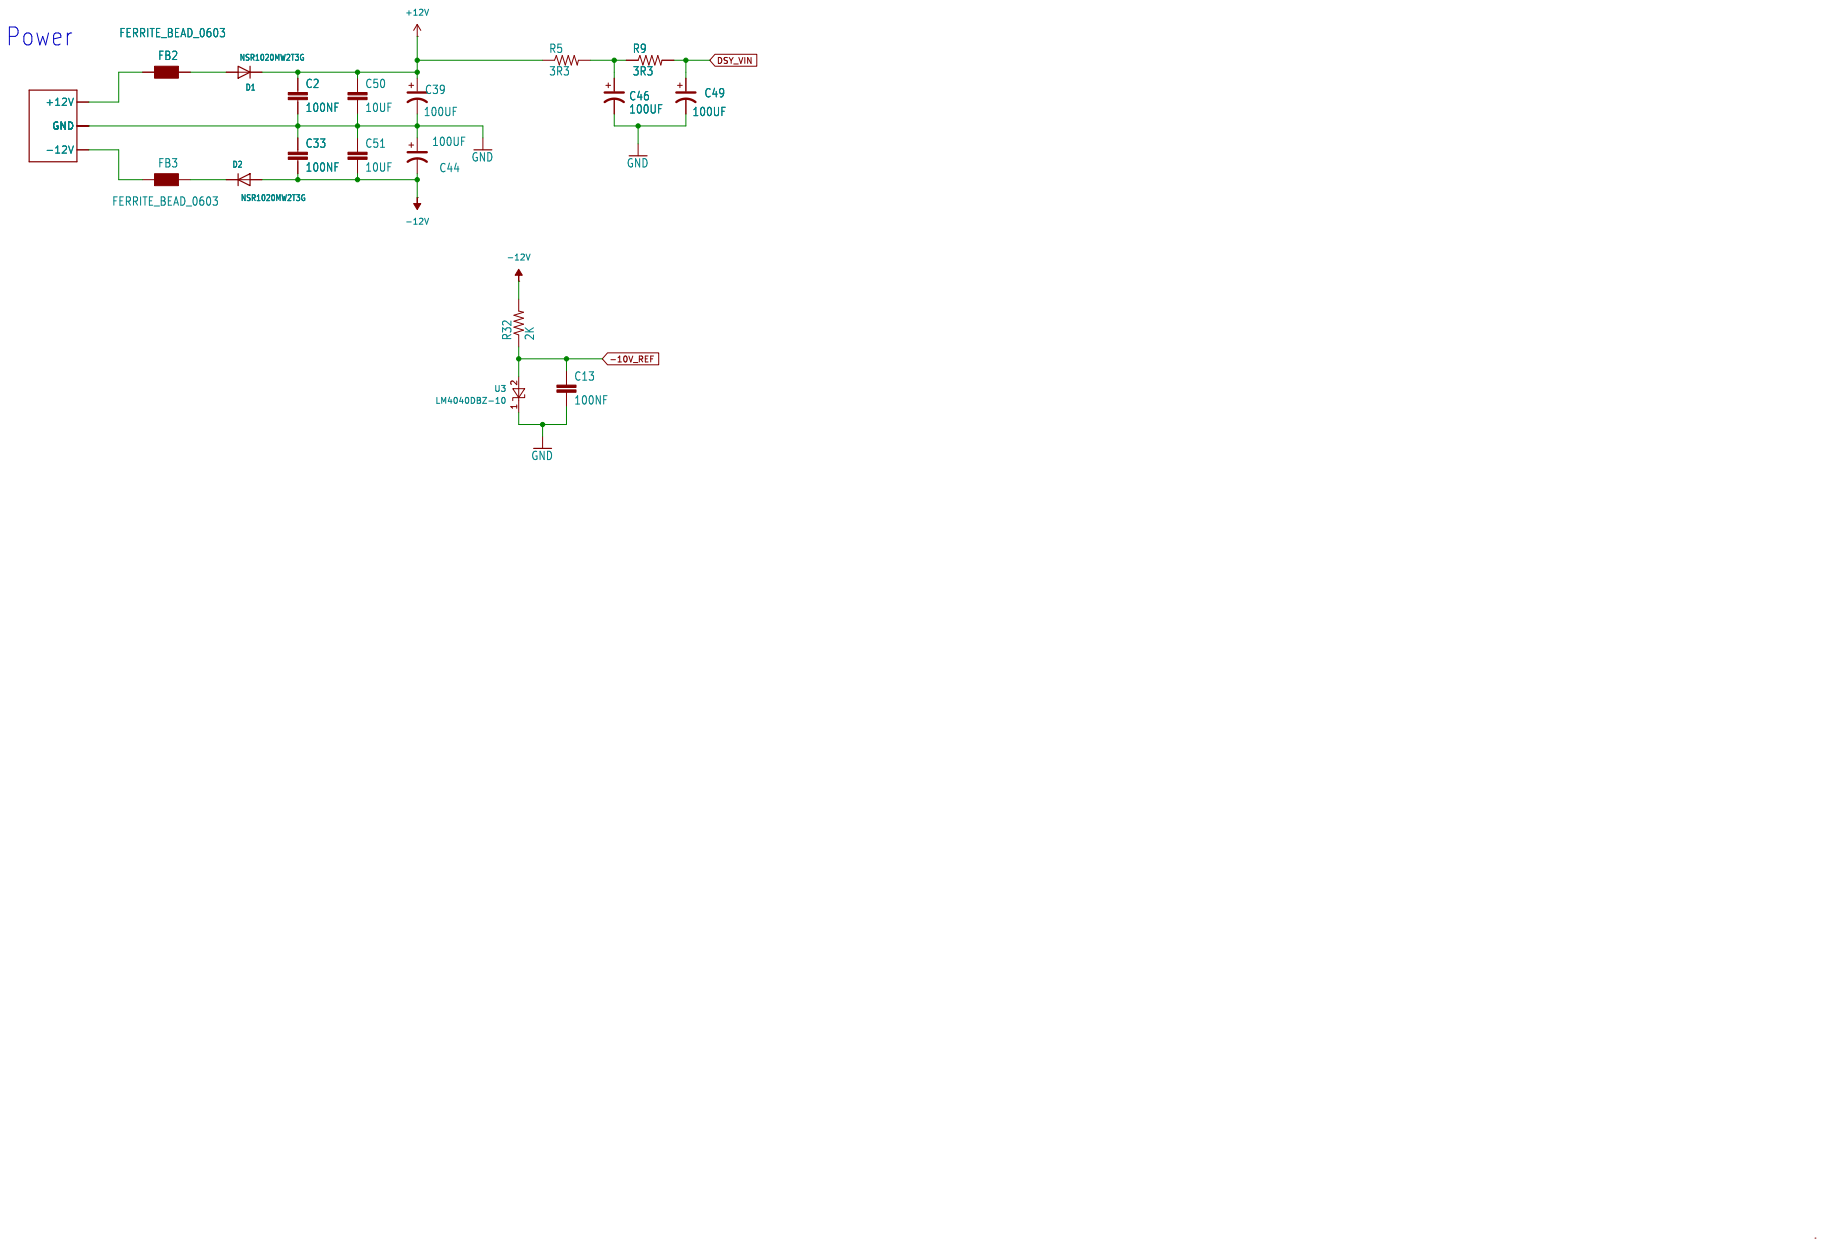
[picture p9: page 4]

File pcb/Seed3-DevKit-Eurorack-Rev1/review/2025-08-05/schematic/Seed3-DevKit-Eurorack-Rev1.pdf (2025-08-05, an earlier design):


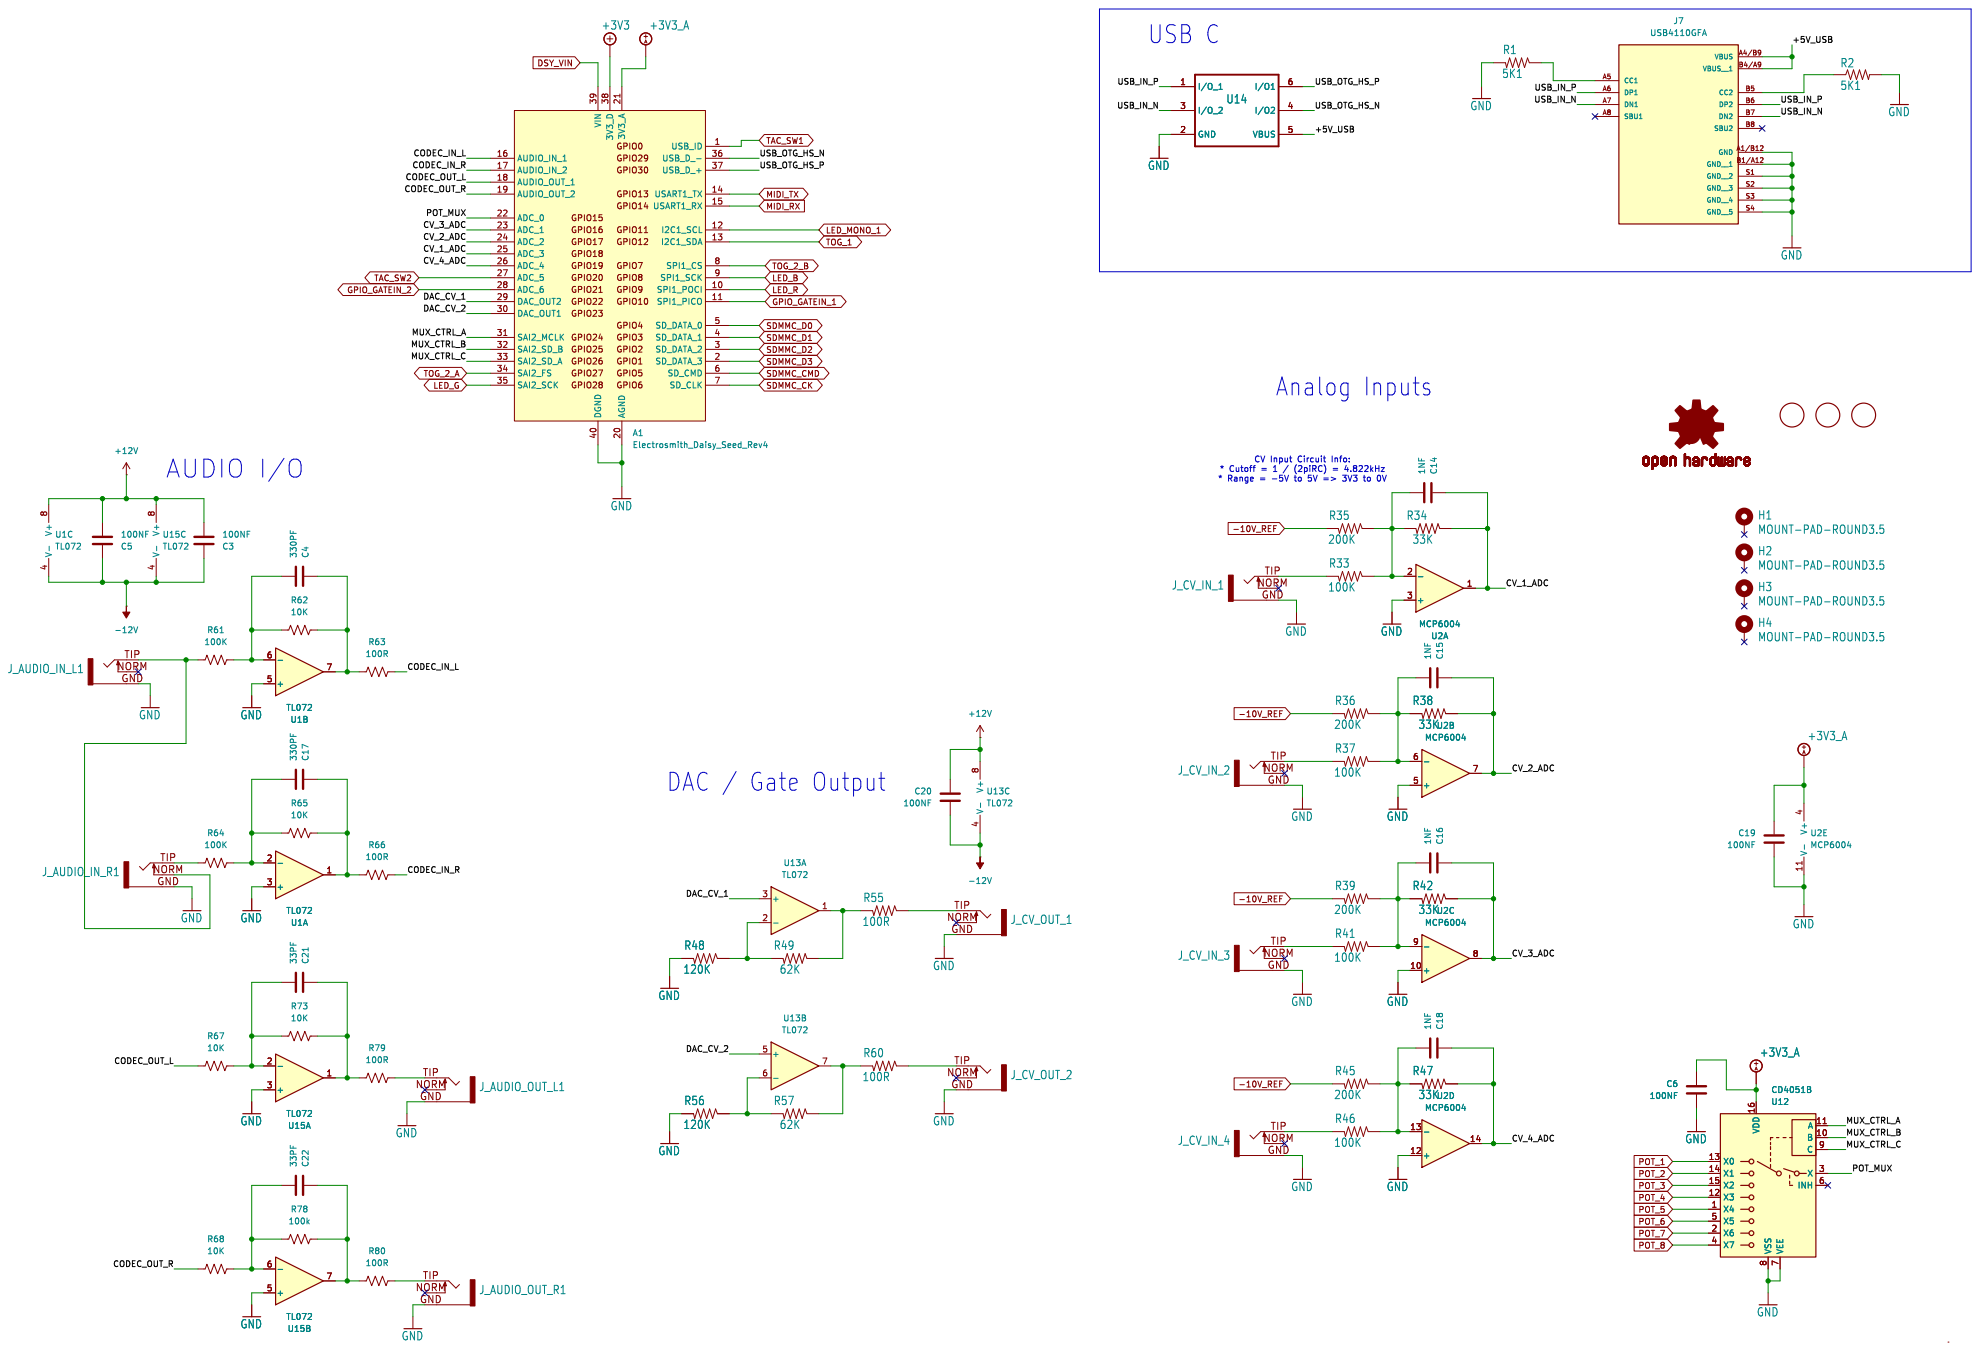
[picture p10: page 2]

CV Input Circuit Info: * Cutoff = 1 / (2piRC) = 4.822kHz

* Range = -5V to 5V => 3V3 to 0V DAC / Gate Output

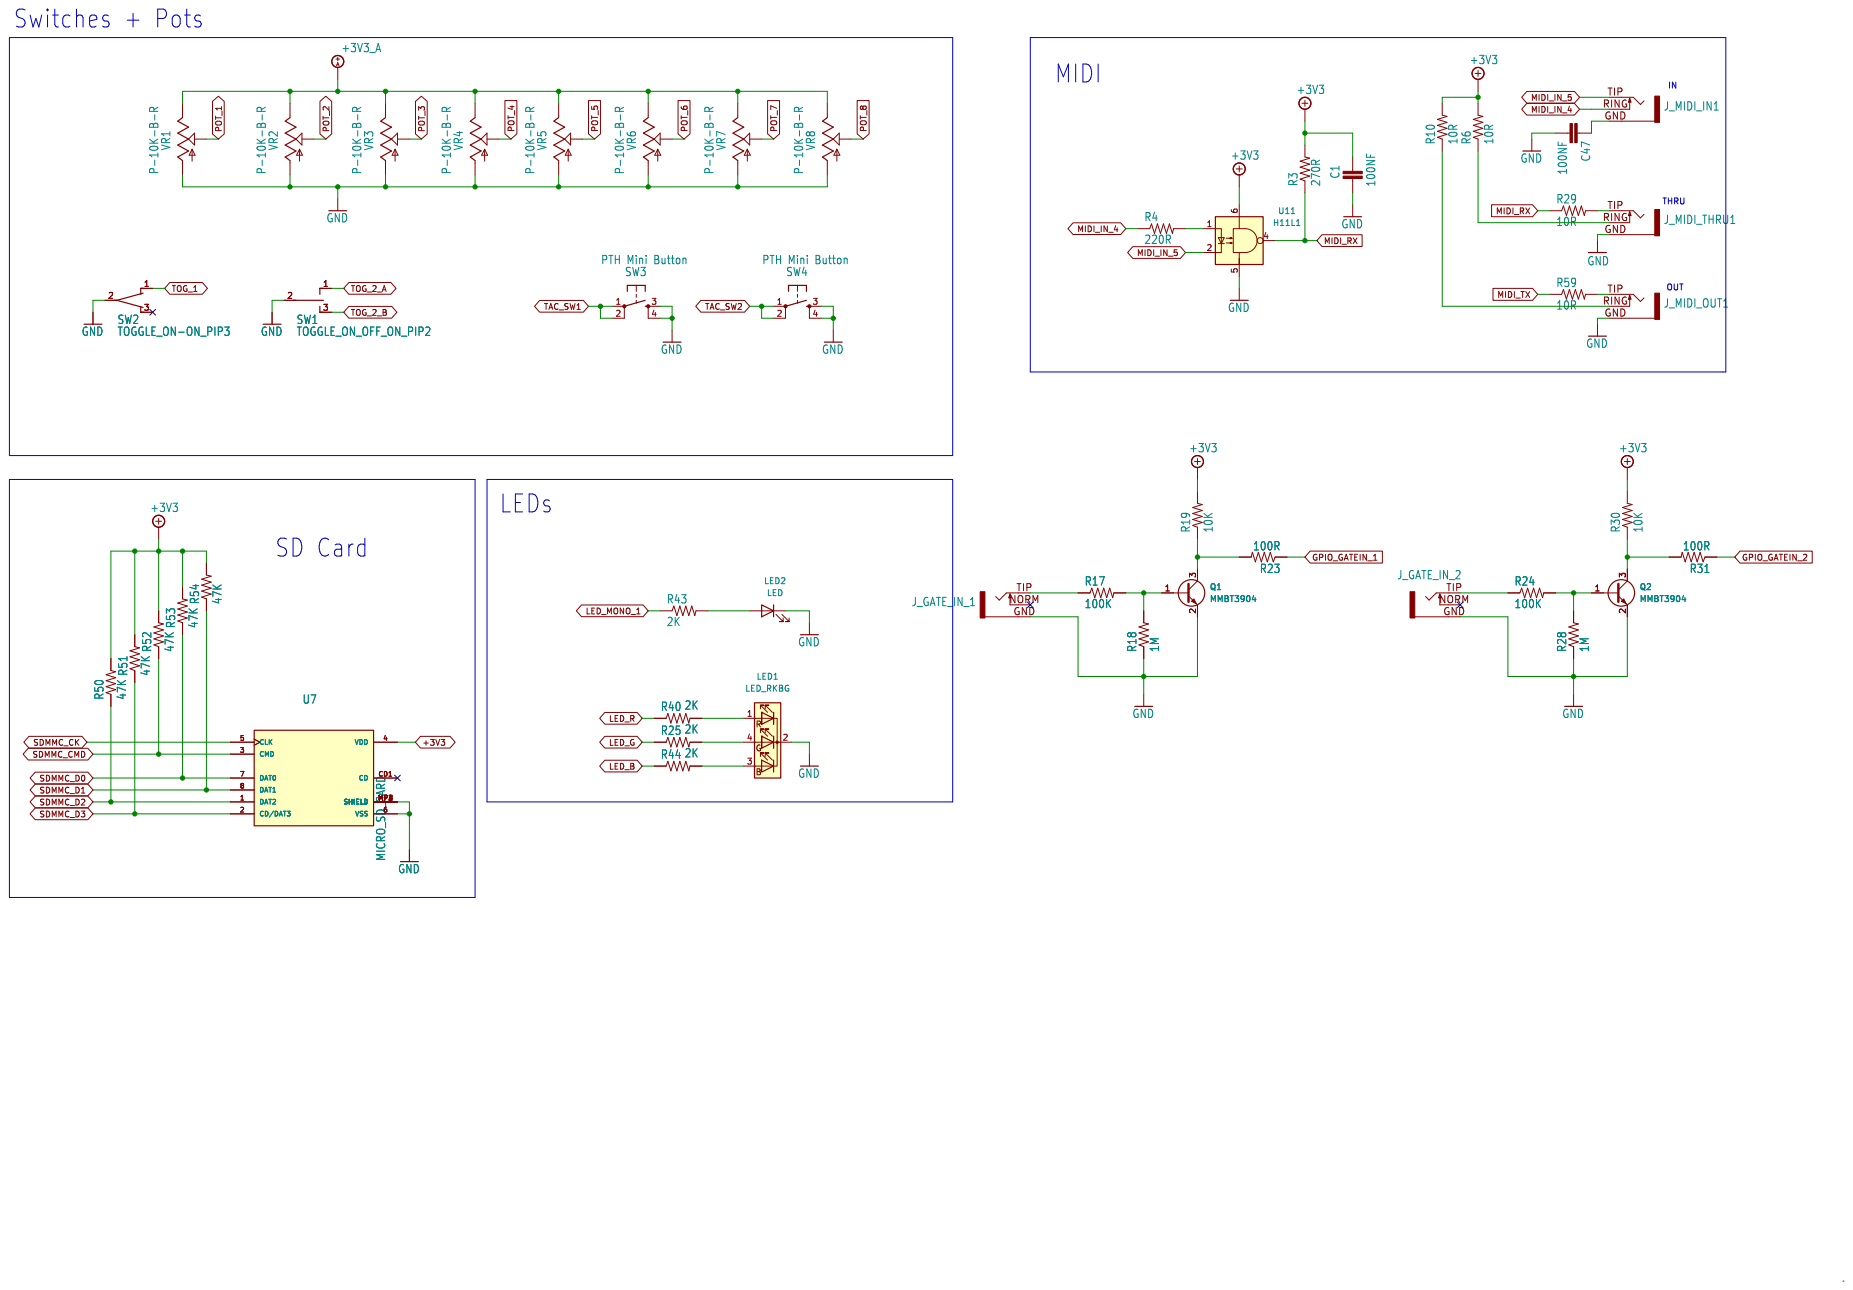
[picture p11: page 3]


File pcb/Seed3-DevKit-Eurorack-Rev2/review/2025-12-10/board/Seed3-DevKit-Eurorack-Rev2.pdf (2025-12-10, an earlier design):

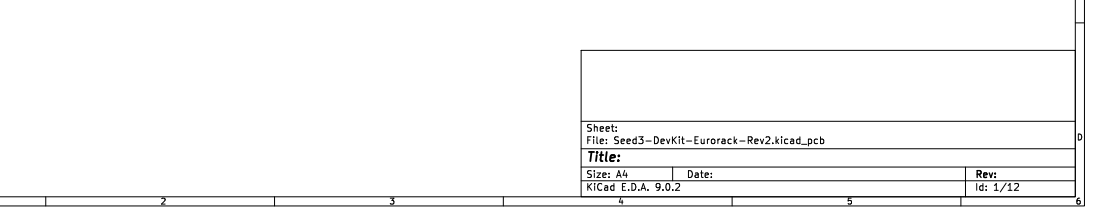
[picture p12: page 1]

Id: 1/12 Title: File: Seed3-DevKit-Eurorack-Rev2.kicad_pcb Sheet:

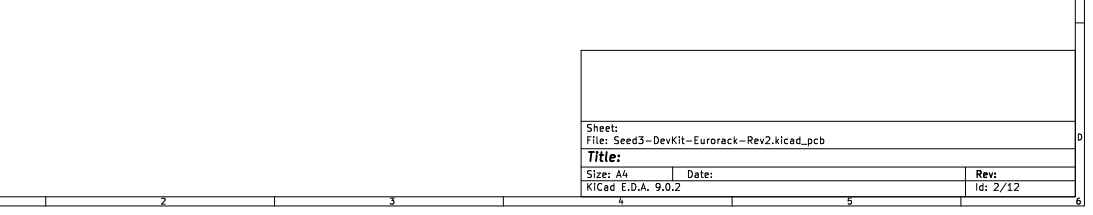
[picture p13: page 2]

Id: 2/12 Title: File: Seed3-DevKit-Eurorack-Rev2.kicad_pcb Sheet:

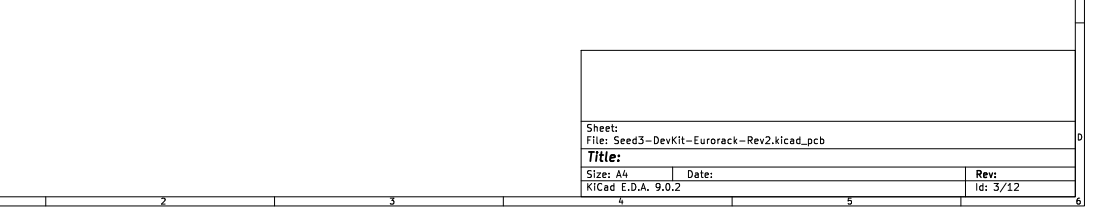
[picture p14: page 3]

Id: 3/12 Title: File: Seed3-DevKit-Eurorack-Rev2.kicad_pcb Sheet:


Id: 4/12 Title: File: Seed3-DevKit-Eurorack-Rev2.kicad_pcb Sheet:


Id: 5/12 Title: File: Seed3-DevKit-Eurorack-Rev2.kicad_pcb Sheet:


Id: 6/12 Title: File: Seed3-DevKit-Eurorack-Rev2.kicad_pcb Sheet:


Id: 7/12 Title: File: Seed3-DevKit-Eurorack-Rev2.kicad_pcb Sheet:


Id: 8/12 Title: File: Seed3-DevKit-Eurorack-Rev2.kicad_pcb Sheet:


Id: 9/12 Title: File: Seed3-DevKit-Eurorack-Rev2.kicad_pcb Sheet:


Id: 10/12 Title: File: Seed3-DevKit-Eurorack-Rev2.kicad_pcb Sheet: FIDUCIAL



Id: 12/12 Title: File: Seed3-DevKit-Eurorack-Rev2.kicad_pcb Sheet:

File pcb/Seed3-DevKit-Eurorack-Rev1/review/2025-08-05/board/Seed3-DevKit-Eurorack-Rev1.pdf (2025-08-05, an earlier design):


Id: 1/12 Title: File: Seed3-DevKit-Eurorack-Rev1.kicad_pcb Sheet:


Id: 2/12 Title: File: Seed3-DevKit-Eurorack-Rev1.kicad_pcb Sheet:


Id: 3/12 Title: File: Seed3-DevKit-Eurorack-Rev1.kicad_pcb Sheet:


Id: 4/12 Title: File: Seed3-DevKit-Eurorack-Rev1.kicad_pcb Sheet:


Id: 5/12 Title: File: Seed3-DevKit-Eurorack-Rev1.kicad_pcb Sheet:


Id: 6/12 Title: File: Seed3-DevKit-Eurorack-Rev1.kicad_pcb Sheet:


Id: 7/12 Title: File: Seed3-DevKit-Eurorack-Rev1.kicad_pcb Sheet:


Id: 8/12 Title: File: Seed3-DevKit-Eurorack-Rev1.kicad_pcb Sheet:


Id: 9/12 Title: File: Seed3-DevKit-Eurorack-Rev1.kicad_pcb Sheet:


Id: 10/12 Title: File: Seed3-DevKit-Eurorack-Rev1.kicad_pcb Sheet: FIDUCIAL


Plated Board Edge: Black White

Type | Not specified

0.01 mm | 1 | 0 1
0.035 mm

copper Bottom Solder Mask

Id: 11/12 Title: File: Seed3-DevKit-Eurorack-Rev1.kicad_pcb Sheet:


Id: 12/12 Title: File: Seed3-DevKit-Eurorack-Rev1.kicad_pcb Sheet:

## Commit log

2025-07-29 initial commit: schematic is done, and almost all parts are on the board.
    [Seed3-DevKit-Eurorack-Rev1.kicad_pcb, Seed3-DevKit-Eurorack-Rev1.kicad_sch, Seed3-DevKit-Eurorack_1.kicad_sch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]
2025-07-29 finished routing board, fixed DRCs, and added cutout to PCB.
    [Seed3-DevKit-Eurorack-Rev1.kicad_pcb, Seed3-DevKit-Eurorack_1.kicad_sch, Seed3-DevKit-Eurorack_2.kicad_sch]
2025-07-29 added first pass of prod/review mats.
    [Seed3-DevKit-Eurorack-Rev1-B_Cu.gbl, Seed3-DevKit-Eurorack-Rev1-B_Fab.gbr, Seed3-DevKit-Eurorack-Rev1-B_Mask.gbs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]
2025-07-29 added missing board info, and regenerated prod mats.
    [Seed3-DevKit-Eurorack-Rev1-B_Cu.gbl, Seed3-DevKit-Eurorack-Rev1-B_Fab.gbr, Seed3-DevKit-Eurorack-Rev1-B_Mask.gbs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]
2025-07-29 a lot of little silk changes.
    [Seed3-DevKit-Eurorack-Rev1-B_Cu.gbl, Seed3-DevKit-Eurorack-Rev1-B_Fab.gbr, Seed3-DevKit-Eurorack-Rev1-B_Mask.gbs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]
2025-08-05 fixed misrouted pin, confirmed DRC
    [Seed3-DevKit-Eurorack-Rev1-B_Cu.gbl, Seed3-DevKit-Eurorack-Rev1-B_Fab.gbr, Seed3-DevKit-Eurorack-Rev1-B_Mask.gbs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]
2025-08-07 added new xlsx BOM for upload that includes PNs
    [Seed3-DevKit-Eurorack-Rev1_bom.xlsx]
2025-08-07 removed second, empty sheet from xlsx file.
    [Seed3-DevKit-Eurorack-Rev1_bom.xlsx]
2025-12-03 rev2 started from rev1 with sch changes (INH pin, and gain typo)
    [Seed3-DevKit-Eurorack-Rev2.kicad_pcb, Seed3-DevKit-Eurorack-Rev2.kicad_sch, Seed3-DevKit-Eurorack_1.kicad_sch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]
2025-12-04 eurorack dev kit rev2 ready to review.
    [Seed3-DevKit-Eurorack-Rev2-B_Cu.gbl, Seed3-DevKit-Eurorack-Rev2-B_Fab.gbr, Seed3-DevKit-Eurorack-Rev2-B_Mask.gbs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]
2025-12-08 updated toggle nets to match sw names better.
    [Seed3-DevKit-Eurorack-Rev2.kicad_pcb, Seed3-DevKit-Eurorack_1.kicad_sch, Seed3-DevKit-Eurorack_2.kicad_sch]
2025-12-08 swapped CV channels, fixed up boxes around pin labels, and updated README with all changes for rev2
    [Seed3-DevKit-Eurorack-Rev2-B_Cu.gbl, Seed3-DevKit-Eurorack-Rev2-B_Fab.gbr, Seed3-DevKit-Eurorack-Rev2-B_Mask.gbs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]
2025-12-08 new prod mats after moving daisy logo
    [Seed3-DevKit-Eurorack-Rev2-B_Cu.gbl, Seed3-DevKit-Eurorack-Rev2-B_Fab.gbr, Seed3-DevKit-Eurorack-Rev2-B_Mask.gbs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]
2025-12-10 regen prod.
    [Seed3-DevKit-Eurorack-Rev2-B_Cu.gbl, Seed3-DevKit-Eurorack-Rev2-B_Fab.gbr, Seed3-DevKit-Eurorack-Rev2-B_Mask.gbs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]
2026-06-25 Rev3 - added missing diode, regenerated review/production mats (#12)
    * opened project in kicad 10
    * Rev3 - Added diode to MIDI Input, regenerated prod, etc.
    * updated jobset for bom grouping, fixed gnd plane, regen gerbers.
    * fixed bom export to match expectations, and regenerated prod. mats.
    [Seed3-DevKit-Eurorack-Rev3-B_Cu.gbl, Seed3-DevKit-Eurorack-Rev3-B_Fab.gbr, Seed3-DevKit-Eurorack-Rev3-B_Mask.gbs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]
2026-10-06 New readme (#14)
    * Revise README for Seed3 Eurorack Dev Kit
    Updated the README to reflect the new Seed3 Eurorack Dev Kit details, including features, specifications, and getting started instructions.
    * Revise MIDI and power specifications in README
    Updated MIDI section and power connector details in README.
    * Specify potentiometer resistance in README
    Updated potentiometer specification to include resistance type.
    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
2026-11-03 updating symbols to built-in kicad libraries, or splitting them to included kicad library to resolve ERCs and eagle-related warnings.
2026-11-03 updated board w/ changes (rotated resistors in sch to avoid needless rotation differences in brd). no more eagle lib usage.
2026-11-03 updated USB footprint and DRC settings to resolve errors.
